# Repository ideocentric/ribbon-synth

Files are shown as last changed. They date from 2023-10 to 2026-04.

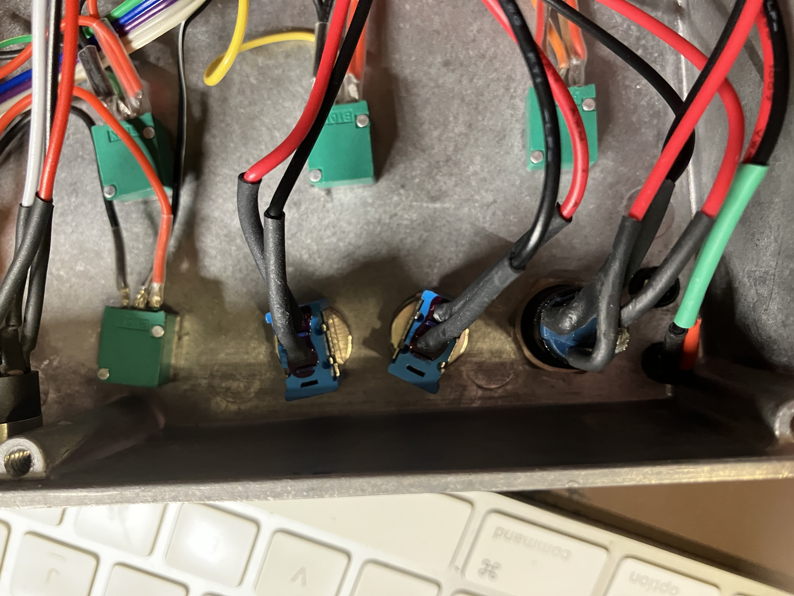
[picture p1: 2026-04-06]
hardware/pcb/absonus-v0.2/hook up/IMG_1601.jpeg

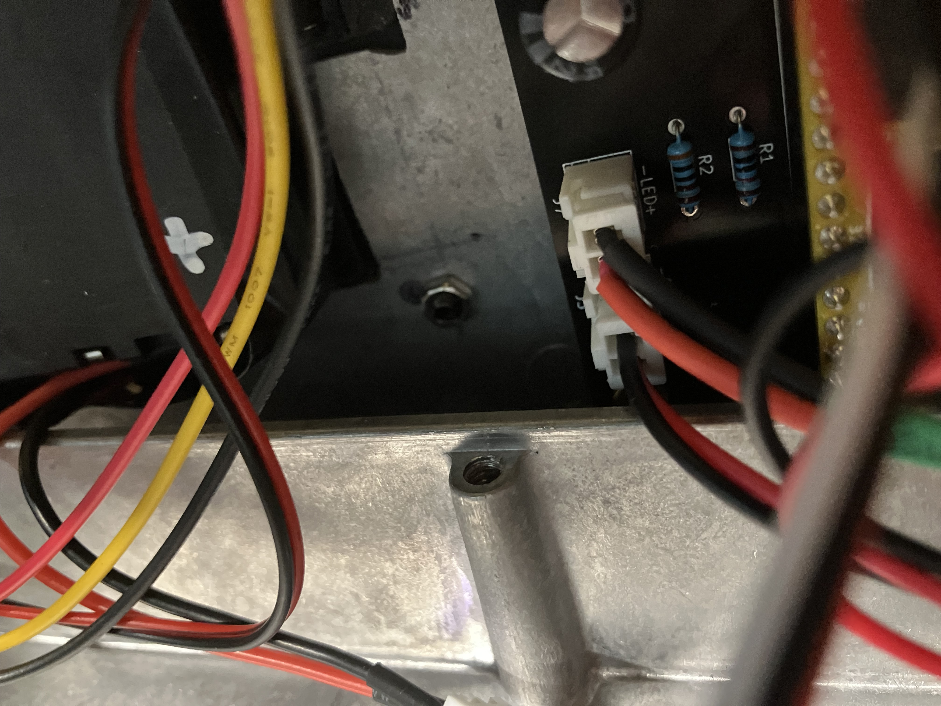
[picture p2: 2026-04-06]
hardware/pcb/absonus-v0.2/hook up/IMG_1600.jpeg

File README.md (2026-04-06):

# absonus — Ribbon Synthesizer

A touch-controlled FM ribbon synthesizer built on the [Electrosmith Daisy Seed](https://electro-smith.com/products/daisy-seed) platform. Pitch is controlled by a 150mm soft-pot ribbon sensor; expression by a force-sensitive resistor. A panel of knobs and switches shapes the FM synthesis, distortion, filter, tremolo, and reverb.

## Repository Structure

```
absonus/
├── firmware/
│   ├── absonus/          Main firmware (DaisyDuino sketch)
│   └── sensor-test/      Utility sketch — reads all panel inputs over serial
│
├── hardware/
│   ├── enclosure/        FreeCAD / DXF / STL files for the enclosure and drill templates
│   ├── pcb/
│   │   ├── absonus-v0.2/ KiCad schematic and PCB layout (current)
│   │   ├── battery-clamp/ 3D-printable clamp for the 18650 battery holder
│   │   └── library/      KiCad component libraries (symbols + footprints)
│   └── testing-panel/    Laser-cut test panel drawings
│
├── bom/
│   ├── pcb-assembly-bom.csv    JLCPCB assembly BOM for the main PCB
│   └── sourced-components.md   Hand-sourced components (pots, sensors, enclosure, etc.)
│
├── docs/
│   ├── design-notes.md         Hardware layout and component design notes
│   ├── firmware-architecture.md Signal chain, module reference, pin mapping
│   └── datasheets/             Component datasheets (FSR, SoftPot, LS18-P, etc.)
│
├── assets/               Photos, renders (to be added)
│
└── archive/
    ├── firmware/         Earlier prototype sketches (fm, fm-chorus, tremor, sensor-test)
    └── hardware/         Earlier PCB revisions (pcb-v0.1, lipo-charger-booster, power-supply)
```

## Documentation

- [Firmware Architecture](docs/firmware-architecture.md) — signal chain, DSP modules, pin mapping, portamento times
- [Design Notes](docs/design-notes.md) — panel layout, Daisy Seed pin assignments, component selection notes
- [Sourced Components BOM](bom/sourced-components.md) — hand-sourced parts with supplier links
- [PCB Assembly BOM](bom/pcb-assembly-bom.csv) — JLCPCB SMT assembly BOM for the main board

## Build

Open `firmware/absonus/absonus.ino` in Arduino IDE with the [DaisyDuino](https://github.com/electro-smith/DaisyDuino) board package installed. Select **Daisy Seed** as the target board.

## Hardware Verification

Before troubleshooting from audio output, flash `firmware/sensor-test/sensor-test.ino` to the Daisy Seed immediately after assembly. It reads every pot, switch, force sensor, and soft-pot and streams their normalized values over serial (9600 baud, 100 ms interval). Use the Arduino Serial Plotter or any serial monitor to confirm each input responds correctly and is wired to the right pin before loading the main firmware.

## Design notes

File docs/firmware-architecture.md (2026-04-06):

# Absonus Firmware Architecture

Firmware for the Absonus ribbon synthesizer. Written in C++ for the Electrosmith Daisy Seed using the DaisyDuino Arduino framework and the DaisySP DSP library.

Source: `firmware/absonus/`

---

## Signal Chain

```
SoftPot (ribbon) ──► pitch (carrierFreq)
FSR (pressure)   ──► gain + gate
                                          ┌─────────┐
                          gate ──────────►│         │
                          gain ──────────►│ Envelope│──► envelopeOut × gain
                                          │  (ADSR) │
                                          └─────────┘
                                                │
                                                ▼
                               ┌─────────────────────────────┐
                  carrierFreq ►│                             │
                   modDepth   ►│       FmChorus              │──► sig (mono)
                   chorusWidth►│  (3-voice FM + detuning)    │
                               └─────────────────────────────┘
                                                │
                                                ▼
                               noiseLevel ──► + WhiteNoise (×0.5 × gain)
                                                │
                                                ▼
                             distortionLevel ──► Cubicnl (cubic waveshaper)
                                                │
                                                ▼
                   filterFreq ──► MoogLadder Filter ◄── filterRes
                                                │
                                                ▼
                                          ┌─────────┐
                  tremoloFreq  ──────────►│         │──► sig × trem (mono)
                  tremoloDepth ──────────►│  Tremor │──► sigl = sig × treml
                  tremoloWidth ──────────►│         │──► sigr = sig × tremr
                                          └─────────┘
                                                │
                                   sigl ────────┤
                                   sigr ────────┤
                                                ▼
                              reverbLevel ──► ReverbSc (SCReverb)
                                                │
                                                ▼
                                 CrossFade (dry/wet blend at reverbLevel)
                                                │
                              volumeLevel ──────┤
                                                ▼
                                     out[0] (L)   out[1] (R)
```

All control parameters are processed through a `Port` (slew/portamento) object before being applied. This prevents zipper noise and audible stepping from ADC readings.

---

## Modules

### FmChorus (`fmchorus.h/.cpp`)

Three-voice frequency modulation synthesizer with built-in chorus detuning.

Each voice is a carrier/modulator oscillator pair (6 oscillators total). The center voice runs at the target pitch. The upper and lower voices are detuned symmetrically by an amount proportional to `width`, up to one equal-tempered semitone. Detuned voices are output at 90% amplitude to preserve the center pitch as dominant.

**Fixed parameters in current patch:**
- Carrier waveform: sawtooth (`WAVE_SAW`)
- Modulator waveform: triangle (`WAVE_TRI`)
- Modulator/carrier ratio: √2 ≈ 1.4142 (equal-tempered tritone)

**Controllable parameters:**
| Parameter | Control | Range | Notes |
|:--|:--|:--|:--|
| Carrier frequency | SoftPot | 55–3520 Hz (A1–A7) | Exponential mapping via `pow(2, normalized × scalar)` |
| Modulation depth | Mod knob (A6\*) | 0.0–1.0 | Scales internally to 0–carrierFreq Hz |
| Chorus width | Chorus knob (A8\*) | 0.0–1.0 | 0 = unison, 1 = ±1 semitone |

*\*See pin mapping below for actual ADC assignments.*

---

### Cubicnl (`cubicnl.h/.cpp`)

Soft-clipping waveshaper using a cubic polynomial. Ported from the Faust `cubicnl.dsp` algorithm by Julius O. Smith III. A DaisySP `DcBlock` filter (pole at 0.999) is applied post-distortion.

| Parameter | Control | Range |
|:--|:--|:--|
| Drive | Distortion knob (A0) | 0.0–1.0 |
| Offset | Fixed | 0.0 (not exposed to panel) |

---

### Tremor (`tremor.h/.cpp`)

Stereo tremolo with panning inspired by the Leslie speaker cabinet. Three internal sine-wave LFOs: one for amplitude modulation and two for stereo panning running at half the tremolo frequency.

The panel uses two toggle switches rather than a continuous knob:

| Switch State | Rate | Depth | Width |
|:--|:--|:--|:--|
| Off (`tremoloOnPin` HIGH) | 0 Hz | 0 | 0 (bypassed) |
| Slow (`tremoloSpeedPin` HIGH) | 1.0 Hz | 0.50 | 0.66 |
| Fast (`tremoloSpeedPin` LOW) | 13.0 Hz | 0.75 | 0.83 |

Slow-to-fast rate transition uses a long portamento time (4 seconds) on `tremoloFreqPortamento` to ramp frequency gradually, mimicking a Leslie speed change.

---

### MoogLadder, ReverbSc, WhiteNoise

Standard DaisySP modules used without modification.

| Module | Control | Range | Notes |
|:--|:--|:--|:--|
| MoogLadder | Cutoff knob (A1\*), Res knob (A5\*) | 20–24000 Hz / 0.0–1.0 | Exponential frequency mapping |
| ReverbSc | Reverb knob (A4\*) | 0.0–1.0 | LP cutoff fixed at 18 kHz; level controls feedback AND dry/wet crossfade |
| WhiteNoise | Noise knob (A2\*) | 0.0–1.0 | Amplitude scaled by ×0.5 × gain |

---

## Envelope and Gate

An ADSR envelope (DaisySP `Adsr`) shapes the amplitude output of `FmChorus`. Gate open/close is driven by the FSR force sensor: gate opens when the normalized FSR reading exceeds `kGateThreshhold` (0.1).

| Segment | Time |
|:--|:--|
| Attack | 100 ms |
| Decay | 100 ms |
| Sustain | 70% |
| Release | 10 ms |

**Frequency hold on gate-off:** When the gate closes, `carrierPortamento` continues slewing toward the *last played frequency* rather than falling back to the minimum. This allows a longer release tail without the pitch dropping to the bottom of the range.

---

## Control Surface Pin Mapping

| ADC Pin | Label | Function | Scaling |
|:--|:--|:--|:--|
| A0 | White | Distortion drive | Linear 0–1 |
| A1 | Purple | Volume | Linear 0–1 |
| A2 | Green | Noise level | Linear 0–1 |
| A3 | Orange | Filter cutoff | Exponential 20–24000 Hz |
| A4 | Pressure | FSR — gain + gate | Linear 0–1, threshold at 0.025 |
| A5 | Ribbon | SoftPot — pitch | Exponential 55–3520 Hz |
| A6 | Yellow | Filter resonance | Linear 0–1 |
| A7 | Blue | Reverb level | Linear 0–1 |
| A8 | Gray | Chorus width | Linear 0–1 |
| A9 | Black | FM modulation depth | Linear 0–1 |
| D13 | SW2 | Tremolo speed (slow/fast) | Digital |
| D14 | SW1 | Tremolo on/off | Digital |

**Sensor thresholds:**
- FSR: readings below 20 (raw) are floored to 0; gate opens above normalized 0.1
- SoftPot: readings below 44 (raw) are floored to 0 to suppress idle noise

---

## Portamento Times

All control parameters are slewed through a `Port` object to eliminate ADC stepping noise. Times below are the slew time constants (seconds to reach ~63% of target).

| Parameter | Slew Time |
|:--|:--|
| Carrier frequency | 10 ms |
| Modulator depth | 10 ms |
| Chorus width | 10 ms |
| Gain | 10 ms |
| Volume | 10 ms |
| Distortion | 10 ms |
| Filter freq | 10 ms |
| Filter res | 10 ms |
| Reverb level | 10 ms |
| Noise level | 10 ms |
| Tremolo frequency | 4000 ms (Leslie ramp) |
| Tremolo depth | 5000 ms |
| Tremolo width | 5000 ms |

---

## Build

Open `firmware/absonus/absonus.ino` in Arduino IDE with the [DaisyDuino](https://github.com/electro-smith/DaisyDuino) board package installed. Select **Daisy Seed** as the target board and upload via the Daisy boot-loader.

### Dependencies
- [DaisyDuino](https://github.com/electro-smith/DaisyDuino) (includes DaisySP)
- All custom DSP modules (`FmChorus`, `Cubicnl`, `Tremor`) are self-contained in the sketch folder.

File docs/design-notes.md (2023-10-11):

# Design Notes

System has 3 potentiometers and 2 toggle switches in the top row.  Second row contains 5 potentiometers.  The third row has a a pressure sensor with a soft potentiometer layered on top of pressure sensor.  Layout of pots, switches and strips are as follows:

Row 1:

| Modulation | Distortion | Chorus Width |  Tremolo Speed| Tremolo On |
|:--|:--|:--|:--|:--|
| 10 - Black | 9 - White | 8 - Gray | SW1 | SW2 |
| A9 | A0 | A8 | D14 | D13 |

Row 2:

| Filter Cutoff | Filter Resonance | Noise | Reverb | Volume |
|:--|:--|:--|:--|:--|
| 3 - Orange | 4 - Yellow | 5 - Green | 6 - Blue | 7 - Purple |
| A3 | A6 | A2 | A7 | A1 |

Touch Sensors:

| Frequency | Pressure |
|:--|:--|
| Soft Pot | Gain |
| A5 | A4 |

Tremolo switches function like a Leslie speaker.  When enabled the speed of the tremolo ramps up to the current speed selection.  The target frequency, depth and stereo width is indicated in the table below:

| Description | Rate | Depth | Width |
|:--|:--|:--|:--|
| Low | 1.0 Hz | 0.5 | 0.66 |
| High | 13 Hz | 0.75 | 0.83 |

Stereo panning is mapped at half the frequency of the tremolo resulting in alternating direction in panning.  The effect is not meant to directly mimic a Leslie speaker, but to simply provide a textural similarity.

Daisy Seed Pin Mappings:

| Pin | Name | Type | Mapping | Notes |
|:-- |:--|:--|:--|:--|
|1 | D0 |  |  |
|2 | D1 |  |  |
|3 | D2 |  |  |
|4 | D3 |  |  |
|5 | D4 |  |  |
|6 | D5 |  |  |
|7 | D6 |  |  |
|8 | D7 |  |  |
|9 | D8 |  |  |
|10 | D9 |  |  |
|11 | D10 |  |  |
|12 | D11 |  |  |
|13 | D12 |  |  |
|14 | D13 | | SW2 |  |
|15 | D14 | | SW1 |  |
|16 | in[0][SIZE] |  |  |
|17 | in[1][SIZE] |  |  |
|18 | out[0][SIZE] |  |  |
|19 | out[1][SIZE] |  |  |
|20 | AGND |  |  |
|21 | 3v3 Analog |  |  |
|22 | A0/D15 | ADC0 | White |  |
|23 | A1/D16 | ADC1 | Purple |  |
|24 | A2/D17 | ADC2 | Green |  |
|25 | A3/D18 | ADC3 | Orange |  |
|26 | A4/D19 | ADC4 | Pressure | 3k Ohm Pulldown |
|27 | A5/D20 | ADC5 | Ribbon | 10k Ohm Pulldown |
|28 | A6/D21 | ADC6 | Yellow |  |
|29 | A7/D22 | ADC7/DAC OUT 2 | Blue |  |
|30 | A8/D23 | ADC8/DAC OUT 1 | Gray |  |
|31 | A9/D24 | ADC9 | Black |  |
|32 | A10/D25 | ADC10 |  |  |
|33 | D26 |  |  |  |
|34 | D27 |  |  |  |
|35 | A11/D28 |  |  |  |
|36 | D29 |  |  |  |
|37 | D30 |  |  |  |
|38 | 3v3 Digital |  |  |  |
|39 | VIN |  | +4v - +17v |  |
|40 | DGND |  |  | | 

Some of the components were challenging to find or were too large for the desired space.  The following list of items are some of the key components required to make this work.  The particular potentiometers were chosen due to their low profile.  The are soldered to a 10 wire ribbon cable.  The colors refer to the matching cable color.

The pressure sensors and soft potentiometers do not match in the available sizes.  In this design I needed a 150mm Soft pot.  Since the Pressure Sensors can be cut down, text available size was 200mm which is cut down to match the usable length of the Soft Pot. 

| Description | Link |
|:--|:--|
| TWTADE 10k Ω Potentiometer | https://www.amazon.com/TWTADE-Amplifier-Potentiometers-Knurled-RK097N-3-10K/dp/B07XQ1Q9RN?th=1 |
| ElectroCookie Solderable Breadboard  | https://www.amazon.com/dp/B07YBYZCTN?ref=ppx_yo2ov_dt_b_product_details&th=1 |
| Ancable 5-Pack 1/8" 3.5mm TRS Stereo Panel Mount Audio AUX Jack | https://www.amazon.com/dp/B07JNC4P7Y?psc=1&ref=ppx_yo2ov_dt_b_product_details |
| uxcell 2 Position 3P SPDT Panel Mount Micro Slide Switch  | https://www.amazon.com/dp/B01NCWDJ18?psc=1&ref=ppx_yo2ov_dt_b_product_details |
| CESS 5.5 x 2.1 mm 5A DC Power Jack Socket  | https://www.amazon.com/dp/B07FK6MMGH?psc=1&ref=ppx_yo2ov_dt_b_product_details |
| Bud Industries Aluminum Enclosure 7.39” L x4.7” W x 1.5” H | https://www.amazon.com/dp/B005T7R82W?psc=1&ref=ppx_yo2ov_dt_b_product_details |
| LS18-P 3-Channel NoBounce IC – PDIP | https://logiswitch.com/shop/nobounce-ics/ls18-p/ |
| Force Sensor FSR Model 408 (200mm length) | https://buyinterlinkelectronics.com/collections/new-standard-force-sensors/products/fsr-model-408-200mm-length |
| Soft Pot (150mm) | https://store.spectrasymbol.com/products/softpot-linear-potentiometer?variant=40669007904883 |

The general design of the instrument is based on a simple FM synthesis.  The module uses 3 carriers and modulator pairs.  The carrier wave form is a sawtooth wave while the modulator is a triangle wave.  The synthesis module is designed to have the ration of the modulator to carrier as configurable, however, in this design it is set to an equal-tempered tritone.  The depth extends the modulation from 0 - the carrier frequency.  The “Chorus Width” is essentially a 3 voice detuning from no detuning  to a full equal-tempered semi-tone.  The upper and lower voices are at a slightly lower amplitude to retain the center frequencies dominance.  The detuned components are a full FM carrier/modulator pair.

Distortion is implemented using Julius O. Smith’s cubicnl.dsp algorithm from Faust ported to the Daisy Seed here.

The Moog Ladder Filter, White Noise and the SCReverb are standard Daisy Seed modules are used here without modification.

One of the initial challenges was to evaluate and map the Soft Pot and Force Sensors.  The Soft Pot is a bit noisy when idle and the full reading needs to be mapped to a usable range.  Additionally, the gate release locks the last set frequency  in order to prevent a fall off to the lowest frequency.  This allows for extending the release time of an envelope.

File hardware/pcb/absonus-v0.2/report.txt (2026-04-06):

Info: Output directory '/Users/matt/Documents/GitHub/synths/daisy/ribbon-synth/hardware/pcb/absonus-v0.2/gerbers' created.
Plotted to '/Users/matt/Documents/GitHub/synths/daisy/ribbon-synth/hardware/pcb/absonus-v0.2/gerbers/absonus-v0.2-F_Cu.gbr'.
Plotted to '/Users/matt/Documents/GitHub/synths/daisy/ribbon-synth/hardware/pcb/absonus-v0.2/gerbers/absonus-v0.2-B_Cu.gbr'.
Plotted to '/Users/matt/Documents/GitHub/synths/daisy/ribbon-synth/hardware/pcb/absonus-v0.2/gerbers/absonus-v0.2-F_Paste.gbr'.
Plotted to '/Users/matt/Documents/GitHub/synths/daisy/ribbon-synth/hardware/pcb/absonus-v0.2/gerbers/absonus-v0.2-B_Paste.gbr'.
Plotted to '/Users/matt/Documents/GitHub/synths/daisy/ribbon-synth/hardware/pcb/absonus-v0.2/gerbers/absonus-v0.2-F_Silkscreen.gbr'.
Plotted to '/Users/matt/Documents/GitHub/synths/daisy/ribbon-synth/hardware/pcb/absonus-v0.2/gerbers/absonus-v0.2-B_Silkscreen.gbr'.
Plotted to '/Users/matt/Documents/GitHub/synths/daisy/ribbon-synth/hardware/pcb/absonus-v0.2/gerbers/absonus-v0.2-F_Mask.gbr'.
Plotted to '/Users/matt/Documents/GitHub/synths/daisy/ribbon-synth/hardware/pcb/absonus-v0.2/gerbers/absonus-v0.2-B_Mask.gbr'.
Plotted to '/Users/matt/Documents/GitHub/synths/daisy/ribbon-synth/hardware/pcb/absonus-v0.2/gerbers/absonus-v0.2-Edge_Cuts.gbr'.
Plotted to '/Users/matt/Documents/GitHub/synths/daisy/ribbon-synth/hardware/pcb/absonus-v0.2/gerbers/absonus-v0.2-F_Courtyard.gbr'.
Created Gerber job file '/Users/matt/Documents/GitHub/synths/daisy/ribbon-synth/hardware/pcb/absonus-v0.2/gerbers/absonus-v0.2-job.gbrjob'.
Info: Done.
Info: Done.

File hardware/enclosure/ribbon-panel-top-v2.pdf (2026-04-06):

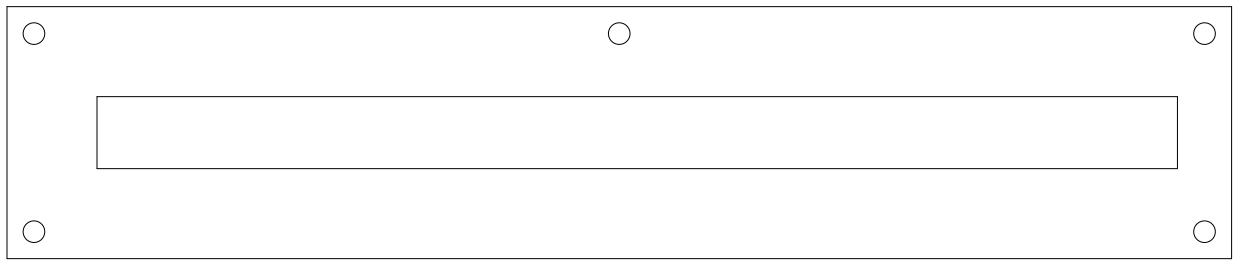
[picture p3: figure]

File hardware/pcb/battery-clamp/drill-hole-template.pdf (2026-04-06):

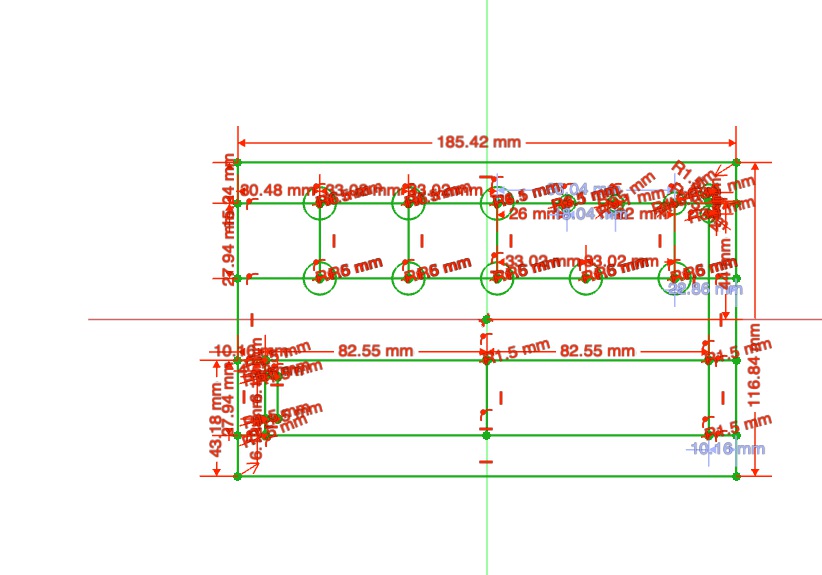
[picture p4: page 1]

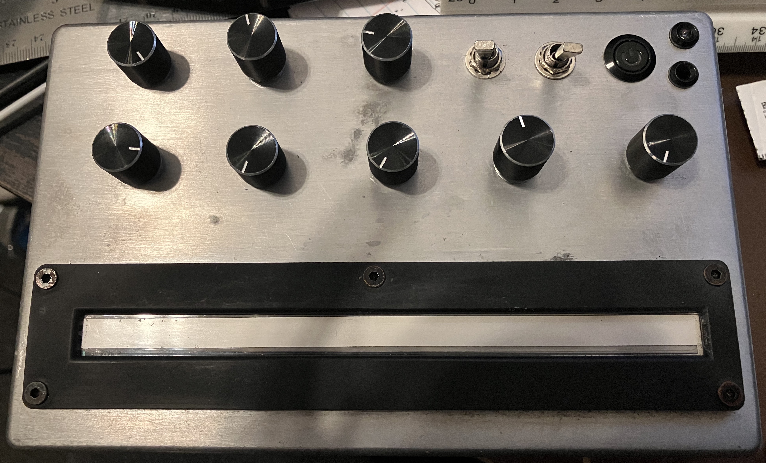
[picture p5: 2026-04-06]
hardware/enclosure/enclosure/top.jpg

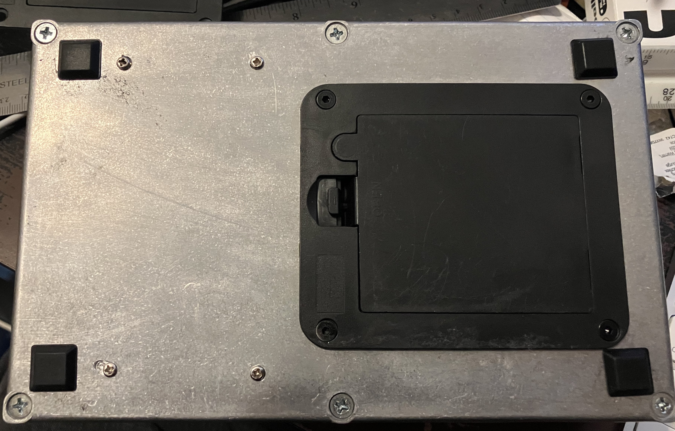
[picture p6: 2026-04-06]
hardware/enclosure/enclosure/back.jpg

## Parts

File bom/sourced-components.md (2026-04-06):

# Sourced Components — Absonus

Components not included in the JLCPCB PCB assembly BOM. These are sourced separately and installed by hand.

| Description | Source / Link |
|:--|:--|
| TWTADE 10kΩ Potentiometer (RK097N-3) | [Amazon](https://www.amazon.com/TWTADE-Amplifier-Potentiometers-Knurled-RK097N-3-10K/dp/B07XQ1Q9RN?th=1) |
| ElectroCookie Solderable Breadboard | [Amazon](https://www.amazon.com/dp/B07YBYZCTN) |
| Ancable 1/8" 3.5mm TRS Stereo Panel Mount Audio Jack (5-pack) | [Amazon](https://www.amazon.com/dp/B07JNC4P7Y) |
| uxcell 2-Position 3P SPDT Panel Mount Micro Slide Switch | [Amazon](https://www.amazon.com/dp/B01NCWDJ18) |
| CESS 5.5×2.1mm 5A DC Power Jack Socket | [Amazon](https://www.amazon.com/dp/B07FK6MMGH) |
| Bud Industries Aluminum Enclosure 7.39"L × 4.7"W × 1.5"H | [Amazon](https://www.amazon.com/dp/B005T7R82W) |
| LS18-P 3-Channel NoBounce IC (PDIP) | [LogiSwitch](https://logiswitch.com/shop/nobounce-ics/ls18-p/) |
| Force Sensor FSR Model 408 (200mm length) | [Interlink Electronics](https://buyinterlinkelectronics.com/collections/new-standard-force-sensors/products/fsr-model-408-200mm-length) |
| SoftPot Linear Potentiometer (150mm) | [Spectra Symbol](https://store.spectrasymbol.com/products/softpot-linear-potentiometer?variant=40669007904883) |

## Notes

- The 10kΩ potentiometers were chosen for their low profile; they are soldered to a 10-wire ribbon cable with color-coded conductors matching the panel layout (see `docs/design-notes.md`).
- The FSR is 200mm and is cut down to match the usable 150mm length of the SoftPot.
- A 3kΩ pulldown resistor is required on the FSR input (A4/D19) and a 10kΩ pulldown on the SoftPot input (A5/D20).

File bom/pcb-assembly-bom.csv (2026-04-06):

Designator | Footprint | Quantity | Value | LCSC Part #
A1 | Electrosmith_Daisy_Seed | 1 | Daisy_Seed_Rev4
A2, A3 | PinHeader_1x20_P2.54mm_Vertical | 2 | PinHeader_1x20_P2.54mm_Vertical | C2897383
C1 | CP_Elec_5x5.4 | 1 | 220uF | C3337
H1, H2, H3, H4 | MountingHole_3.2mm_M3 | 4 | M3
J1 | JST_SH_SM04B-SRSS-TB_1x04-1MP_P1.00mm_Horizontal | 1 | i2c Qwiic | C160404
J10 | IDC-Header_2x05_P2.54mm_Vertical | 1 | 2x5 IDC | C4749194
J3 | JST_XH_B2B-XH-A_1x02_P2.50mm_Vertical | 1 | DC 5V | C158012
J4 | JST_XH_B2B-XH-A_1x02_P2.50mm_Vertical | 1 | Pressure | C158012
J5 | JST_XH_B2B-XH-A_1x02_P2.50mm_Vertical | 1 | SW1 | C158012
J6 | JST_XH_B2B-XH-A_1x02_P2.50mm_Vertical | 1 | SW2 | C158012
J7 | JST_XH_B2B-XH-A_1x02_P2.50mm_Vertical | 1 | LED | C158012
J8 | JST_XH_B3B-XH-A_1x03_P2.50mm_Vertical | 1 | Position | C144394
J9 | JST_XH_B3B-XH-A_1x03_P2.50mm_Vertical | 1 | Audio Out | C144394
R1 | 0603 | 1 | 10k | C15401
R2 | 0603 | 1 | 3k | C4211
U1 | DIP787W45P254L927H533Q8 | 1 | LS18-P | C5289485

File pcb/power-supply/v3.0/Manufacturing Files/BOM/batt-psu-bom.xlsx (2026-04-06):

Comment | MFR | MFR-PN | Designator | Footprint | JLCPCB Part #（optional）
BH-18650-A5BJ001-2D | MYOUNG | BH-18650-A5BJ001-2D | BT1, BT2 | Battery:BatteryHolder_MPD_BH-18650-PC2 | C19184083
CL10A106MA8NRNC | Samsung Electro-Mechanics | CL10A106MA8NRNC | C1, C7, C10, C16 | Capacitor_SMD:C_0603_1608Metric | C96446
RVT1A471M0607 | Honor Elec | RVT1A471M0607 | C2 | Capacitor_SMD:CP_Elec_6.3x7.7 | C87858
0603B104K250CT | Walsin Tech Corp | 0603B104K250CT | C3, C4, C5, C13 | Capacitor_SMD:C_0603_1608Metric | C83054
0603X105M250NT | FH (Guangdong Fenghua Advanced Tech) | 0603X105M250NT | C6, C14 | Capacitor_SMD:C_0603_1608Metric | C2857985
CL21A226MAYNNNE | Samsung Electro-Mechanics | CL21A226MAYNNNE | C8 | Capacitor_SMD:C_0603_1608Metric | C602037
SS34 | JUXING | SS34 | D3 | Diode_SMD:D_SMA | C3011102
B2B-XH-A(LF)(SN) | JST | B2B-XH-A(LF)(SN) | J1, J2, J3, J5, J6, J7 | Connector_JST:JST_XH_B2B-XH-A_1x02_P2.50mm_Vertical | C158012
SLO1040H100MTT | Sunltech Tech | SLO1040H100MTT | L1 | Inductor_SMD:L_Wuerth_HCI-1040 | C182194
SI2347DS-T1-GE3 | Vishay Intertech | SI2347DS-T1-GE3 | Q1, Q2 | Package_TO_SOT_SMD:SOT-23 | C145002
FS3402 | FOSAN | FS3402 | Q3, Q4, Q5 | Package_TO_SOT_SMD:SOT-23 | C2926128
FRC0603J474 TS | FOJAN | FRC0603J474 TS | R1 | Resistor_SMD:R_0603_1608Metric | C2907171
FRC0603J331 TS | FOJAN | FRC0603J331 TS | R2, R3, R7, R9, R11 | Resistor_SMD:R_0603_1608Metric | C2907152
FRC0603J202 TS | FOJAN | FRC0603J202 TS | R4 | Resistor_SMD:R_0603_1608Metric | C2907137
FRC0603F6201TS | FOJAN | FRC0603F6201TS | R5 | Resistor_SMD:R_0603_1608Metric | C2907054
FRC0603J202 TS | FOJAN | FRC0603J202 TS | R6 | Resistor_SMD:R_0603_1608Metric | C2907137
25121WF800MT4E | UNI-ROYAL(Uniroyal Elec) | 25121WF800MT4E | R12 | Resistor_SMD:R_2512_6332Metric | C421509
MIC39102YM-TR | Microchip Tech | MIC39102YM-TR | U1 | Package_SO:SOIC-8_3.9x4.9mm_P1.27mm | C627993
HY2120-CB | HYCON Tech | HY2120-CB | U3 | Package_TO_SOT_SMD:SOT-23-6 | C116509
LTC4412ES6#TRPBF | Analog Devices | LTC4412ES6#TRPBF | U4 | Package_TO_SOT_SMD:TSOT-23-6 | C514442
CN3302 | ShangHai Consonance Elec | CN3302 | U5 | Package_SO:SOIC-8_3.9x4.9mm_P1.27mm | C559039

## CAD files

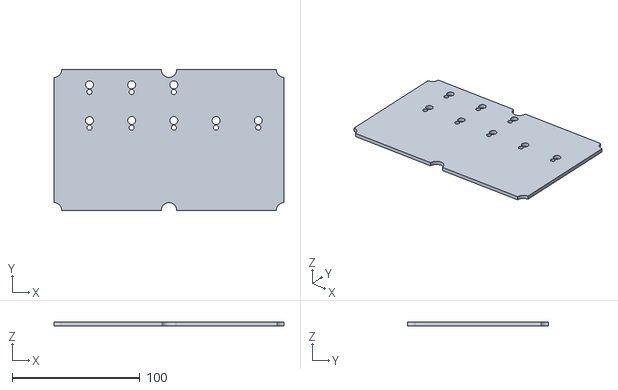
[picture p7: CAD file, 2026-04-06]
hardware/enclosure/internal-drill-holes-test.stl
180.0 x 110.0 x 3.00

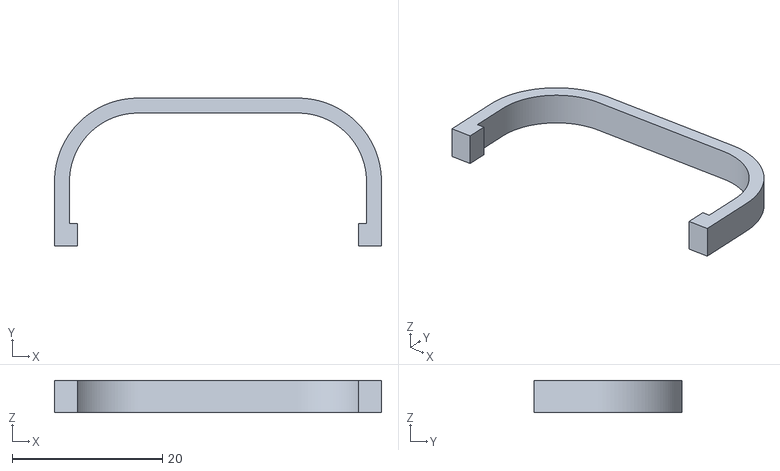
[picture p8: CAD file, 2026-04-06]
hardware/pcb/battery-clamp/battery-clamp-BodyPad.stl
43.6 x 19.7 x 4.30

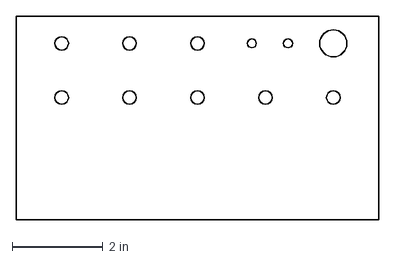
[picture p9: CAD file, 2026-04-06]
hardware/testing-panel/test-panel.dxf
8.00 x 4.50 in

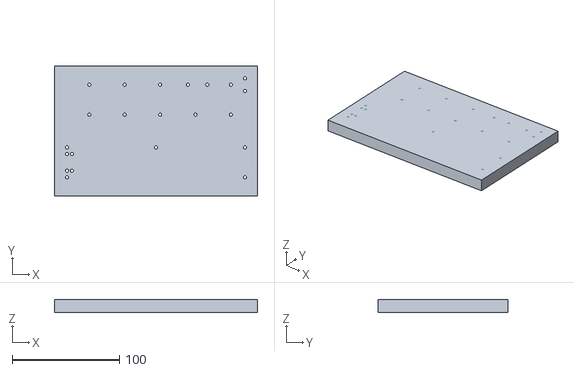
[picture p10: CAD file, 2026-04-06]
hardware/enclosure/drill-hole-template-v5.stl
189.4 x 120.8 x 12.0

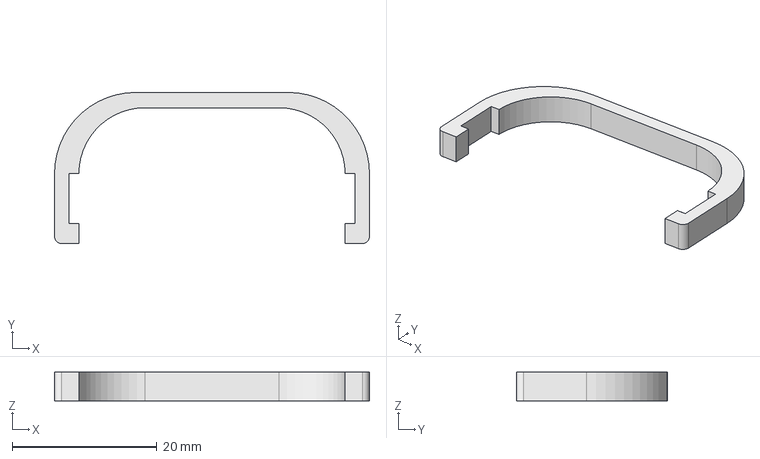
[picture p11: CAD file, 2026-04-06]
hardware/pcb/battery-clamp/battery-clamp-v3.FCStd
43.6 x 20.9 x 4.00 mm

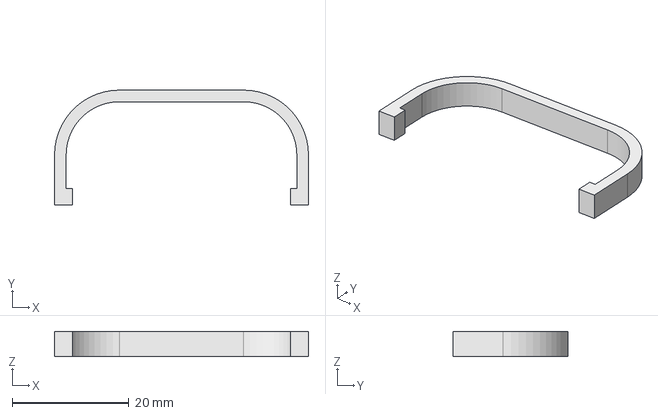
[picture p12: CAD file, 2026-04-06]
hardware/pcb/battery-clamp/battery-clamp.FCStd
43.6 x 19.7 x 4.30 mm

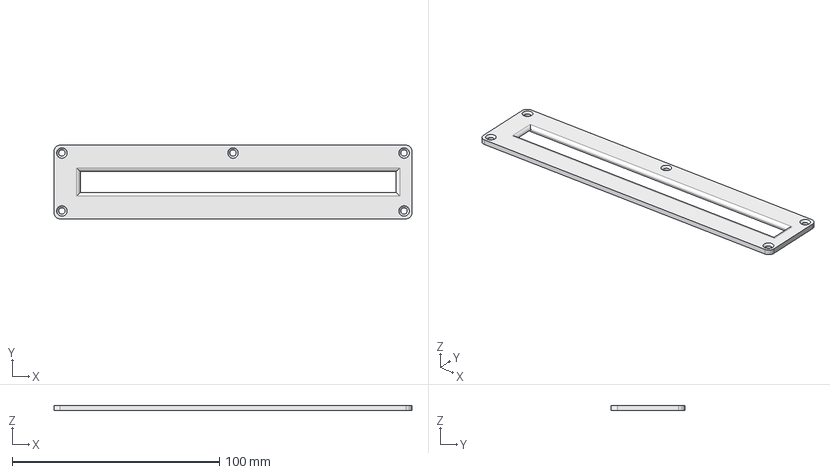
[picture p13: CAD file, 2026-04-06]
hardware/enclosure/ribbon-panel-rev-1.0.FCStd
172.7 x 35.6 x 2.50 mm

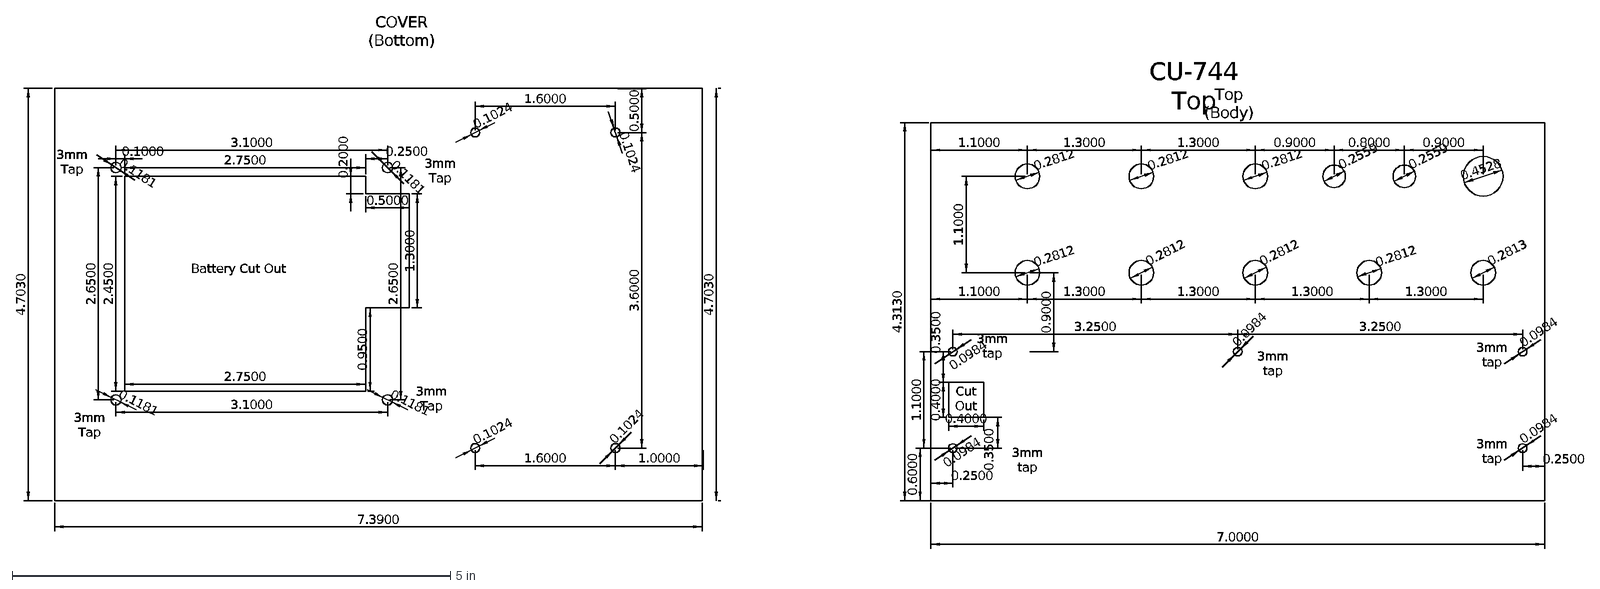
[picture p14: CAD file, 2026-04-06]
hardware/enclosure/#bud-cu-477-drill-patterns.dxf
7.3900
4.7030
COVER (Bottom)
4.3130
7.0000
3.2500
1.1000
0.4000
0.3500
0.6000
0.0984
0.2559
0.2812
0.2813
Top (Body)
0.2500
1.3000
0.9000
3mm tap
CU-744 Top
1.6000
0.5000
3.6000
1.0000
0.1024
3.1000
2.6500
0.1000
2.7500
2.4500
0.9500
0.2000
0.1181
3mm Tap
Battery Cut Out
Cut Out
0.4528
0.8000

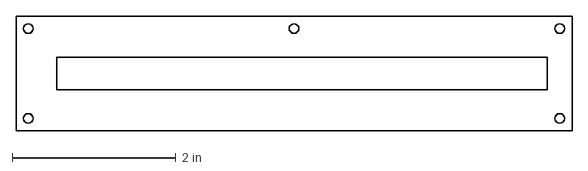
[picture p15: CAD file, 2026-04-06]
hardware/enclosure/ribbon-panel-top-rev-1.0.dxf
6.80 x 1.40 in

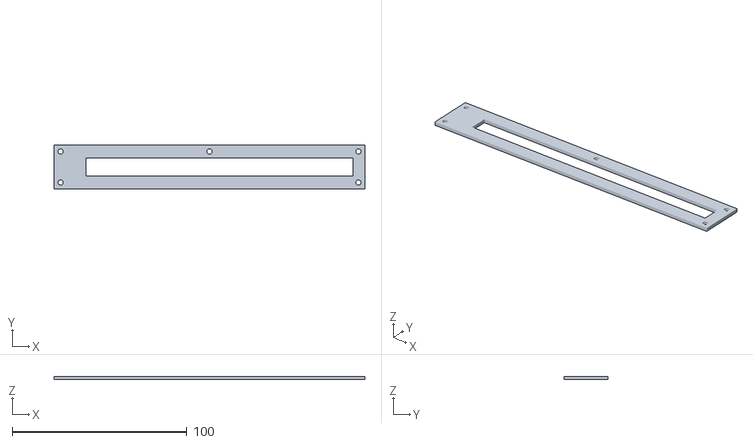
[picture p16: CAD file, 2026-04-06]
hardware/enclosure/ribbon-panel-larger.stl
177.8 x 25.3 x 2.00

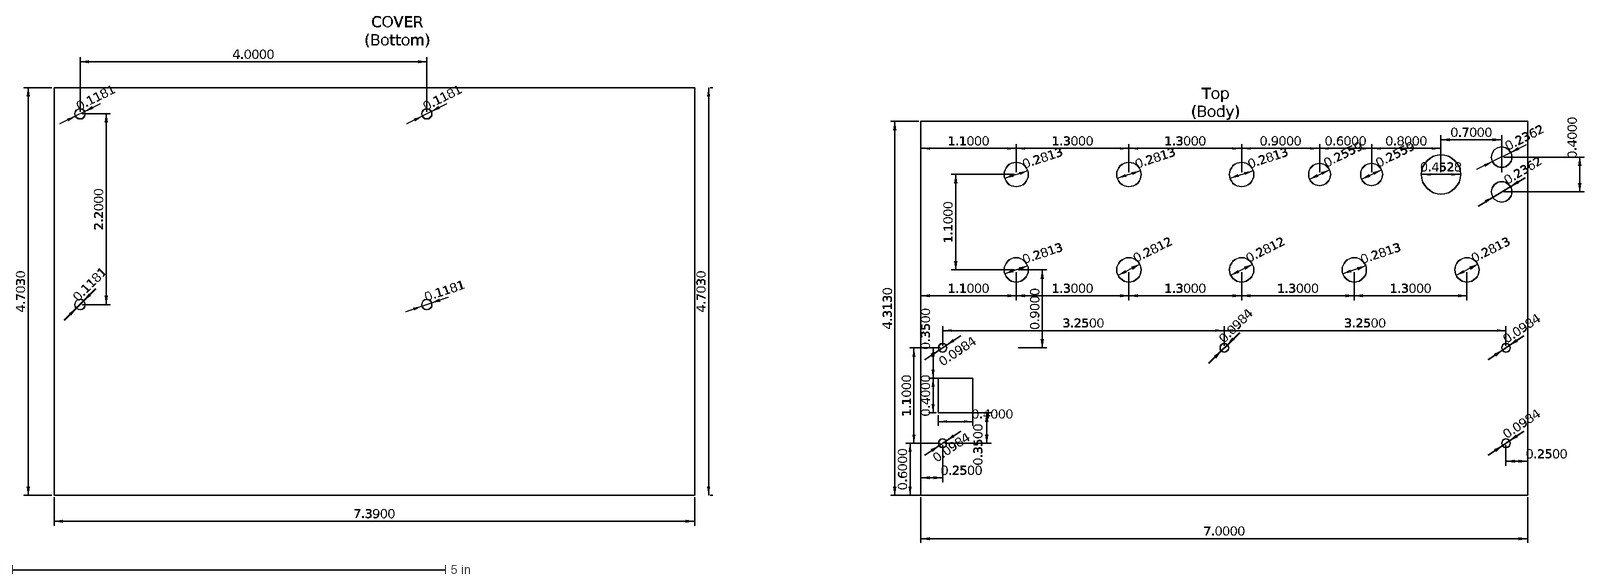
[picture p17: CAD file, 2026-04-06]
hardware/enclosure/bud-industries-custom-drill.dxf
7.3900
4.7030
4.0000
2.2000
0.1181
COVER (Bottom)
4.3130
7.0000
3.2500
1.1000
0.4000
0.3500
0.6000
0.0984
0.2362
0.4528
0.2559
0.2813
0.2812
Top (Body)
0.2500
1.3000
0.9000
0.8000
0.7000

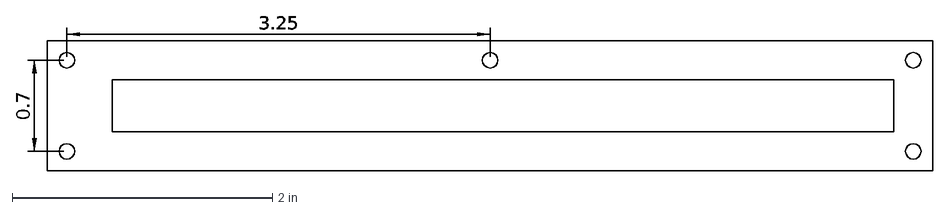
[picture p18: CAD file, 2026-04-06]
hardware/enclosure/#ribbon-panel-top.dxf
3.25
0.7

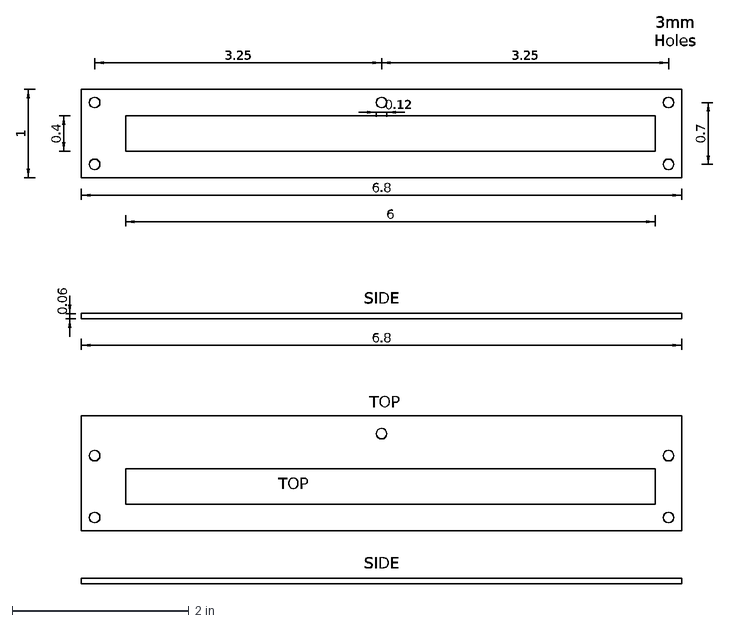
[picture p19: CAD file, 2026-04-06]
hardware/enclosure/#ribbon-panel-v2.dxf
TOP
SIDE
6.8
6
0.4
3.25
0.7
1
0.06
0.12
3mm Holes

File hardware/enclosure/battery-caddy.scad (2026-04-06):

difference(){
cube([2.4,2.8,1]);
translate([0.1,-0.1,0.1]){
cube([2.2,2.8,2]);
};

translate([0.4, 0.4, -0.1]){
 cylinder(0.4,0.06,0.06, $fn=24);
};
translate([2, 0.4, -0.1]){
 cylinder(0.4,0.06,0.06, $fn=24);
};

translate([0.4, 2.4, -0.1]){
 cylinder(0.4,0.06,0.06, $fn=24);
};
translate([2, 2.4, -0.1]){
 cylinder(0.4,0.06,0.06, $fn=24);
};

};

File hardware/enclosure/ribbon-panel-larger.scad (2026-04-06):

$fn=96;
px = 7 * 25.4;
py = .8 * 25.4 +3 +2;
pz = 2;

ix = 6 * 25.4;
iy = 0.4 * 25.4;
iz = 2 + 2;  // adding 2 for offset

radius = 3/2;
offset = (py-iy)/4;

module hole(x,y) 
{
    translate([x,y,-1])
    {
        cylinder(4,radius,radius);
    };
};
module plate() {
    cube([px, py, pz]);
};

module innerCutout() {
    translate([px-7-ix,(py-iy)/2,-1])
    {
        cube([ix,iy,iz]);
    };
}

difference()
{
    plate();
    innerCutout();
    
    hole(offset,offset);
    hole(offset,py-offset);
    hole(px-offset,offset);
    hole(px-offset,py-offset); 
    hole(px/2,py-offset); 
};

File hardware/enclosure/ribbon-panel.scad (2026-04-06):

difference(){
union(){
cube([0.3, 6.8, 0.0625]);
translate([0.3, 0.0]) {
    cube([0.4,0.4, 0.0625]);
    };
    translate([0.7,0,0]) {
        cube([0.3, 6.8, 0.0625]);
        };
 translate([0.3,6.5,0.0]){
     cube([0.4,0.3, 0.0625]);
 };
};

translate([0.13,0.13,-0.05]){
cylinder(0.1625,0.06, 0.06, $fn=45);
};
translate([0.87,0.13,-0.05]){
cylinder(0.1625,0.06, 0.06, $fn=45);
};

translate([0.13,6.67,-0.05]){
cylinder(0.1625,0.06, 0.06, $fn=45);
};
translate([0.87,6.67,-0.05]){
cylinder(0.1625,0.06, 0.06, $fn=45);
};

translate([0.13,3.4,-0.05]){
cylinder(0.1625,0.06, 0.06, $fn=45);
};


};

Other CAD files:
hardware/enclosure/bottom-drill-holes.FCStd
hardware/enclosure/internal-drill-holes-blank.stl
hardware/enclosure/internal-drill-holes.step
hardware/enclosure/bottom-drill-holes-BodyPad.stl
hardware/enclosure/drill-hole-template.FCStd
hardware/enclosure/#internal-drill-holes.dxf
hardware/enclosure/18560-battery-case.FCStd
hardware/enclosure/bud-cu-477-drill-patterns.dxf
hardware/enclosure/drill-hole-template-v1.stl
hardware/enclosure/drill-hole-template-v2.stl
hardware/enclosure/drill-hole-template-v3.stl
hardware/enclosure/drill-hole-template-v4.stl
hardware/enclosure/enclosure-v2.dxf
hardware/enclosure/internal-drill-holes.FCStd
hardware/enclosure/internal-drill-holes.dxf
hardware/enclosure/internal-drill-holes.stl
hardware/enclosure/ribbon-panel-rev-1.0.stl
hardware/enclosure/ribbon-panel-rev-1.2.step
hardware/enclosure/ribbon-panel-rev-1.2.stl
hardware/enclosure/ribbon-panel-top.dxf
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

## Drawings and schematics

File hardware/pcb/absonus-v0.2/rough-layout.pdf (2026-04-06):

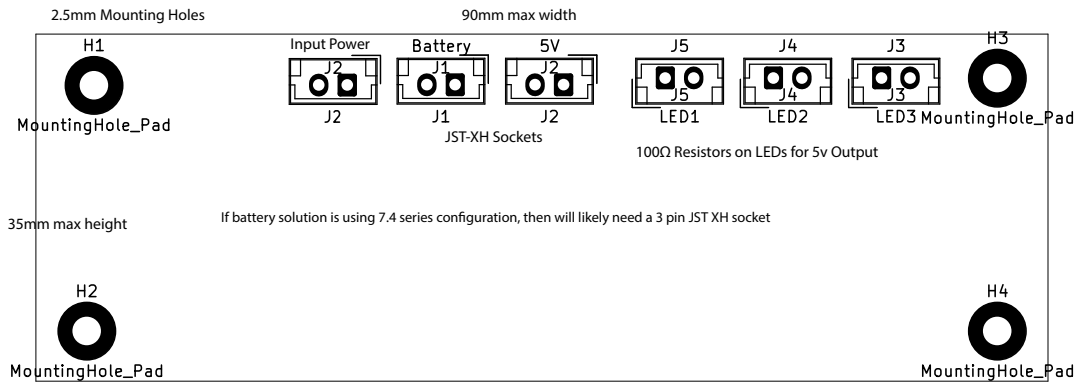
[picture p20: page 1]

100Ω Resistors on LEDs for 5v Output

If battery solution is using 7.4 series conguration, then will likely need a 3 pin JST XH socket

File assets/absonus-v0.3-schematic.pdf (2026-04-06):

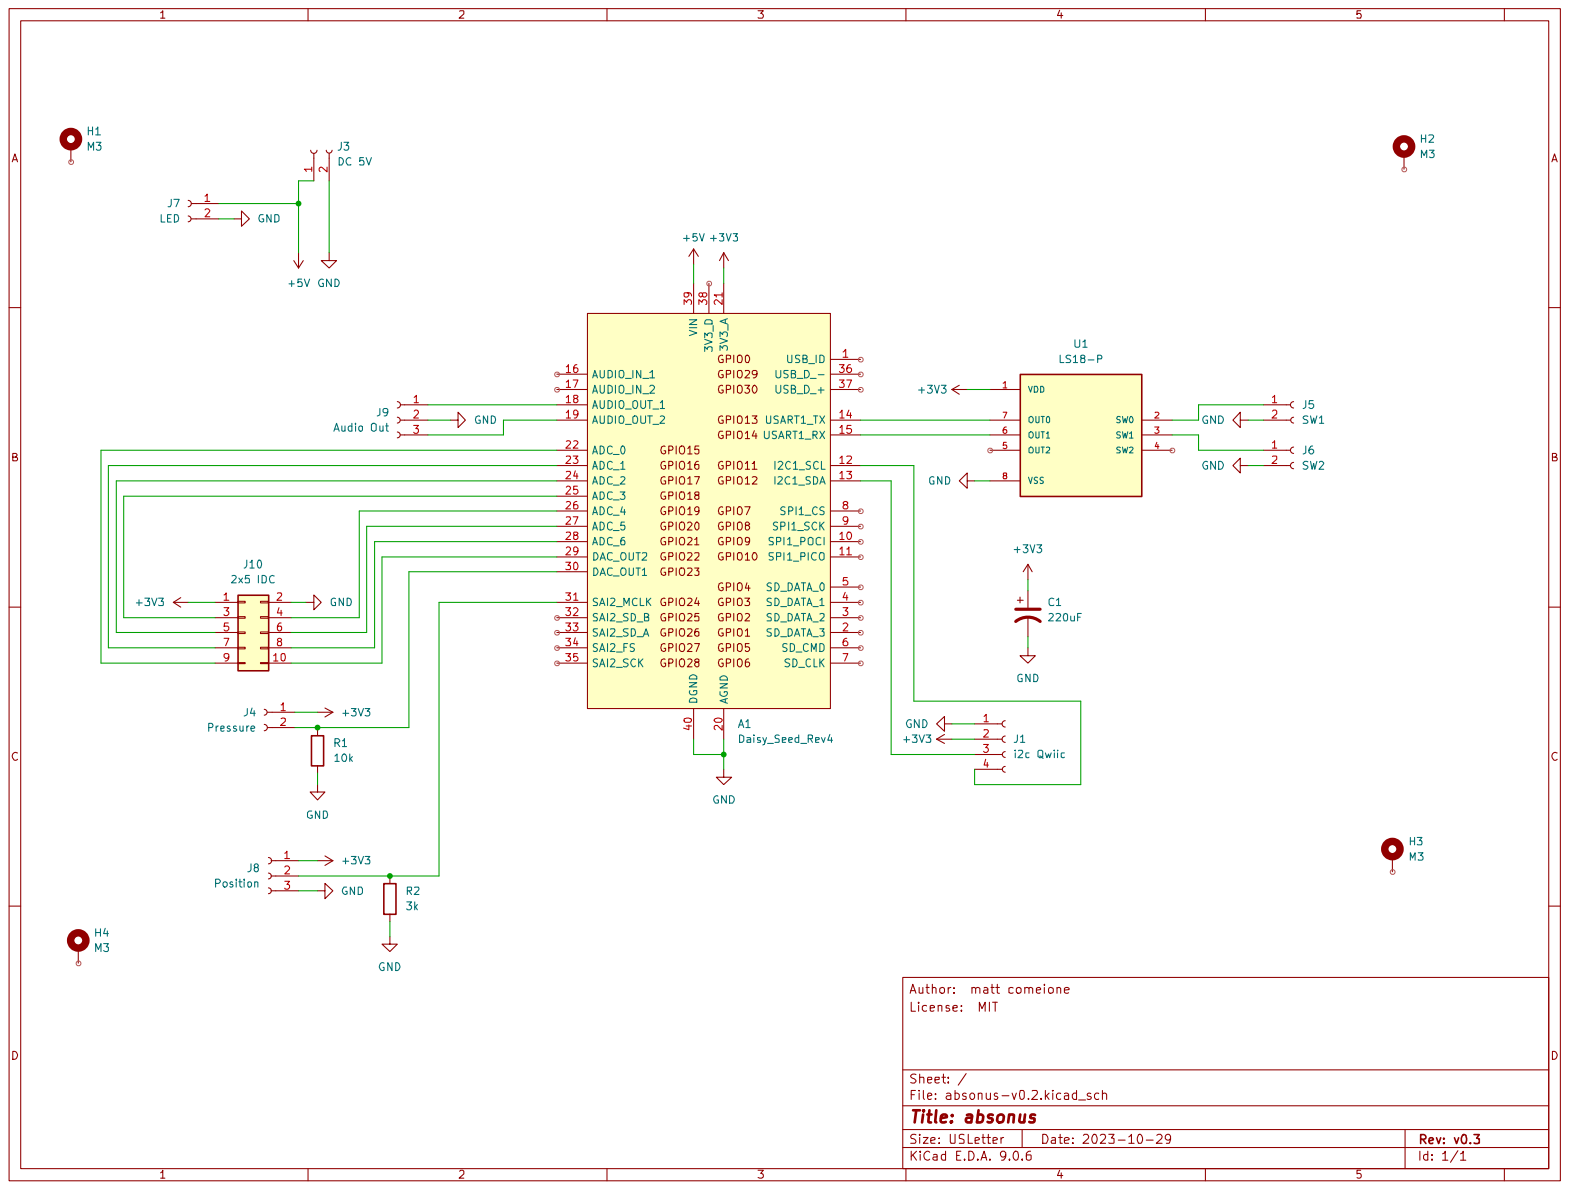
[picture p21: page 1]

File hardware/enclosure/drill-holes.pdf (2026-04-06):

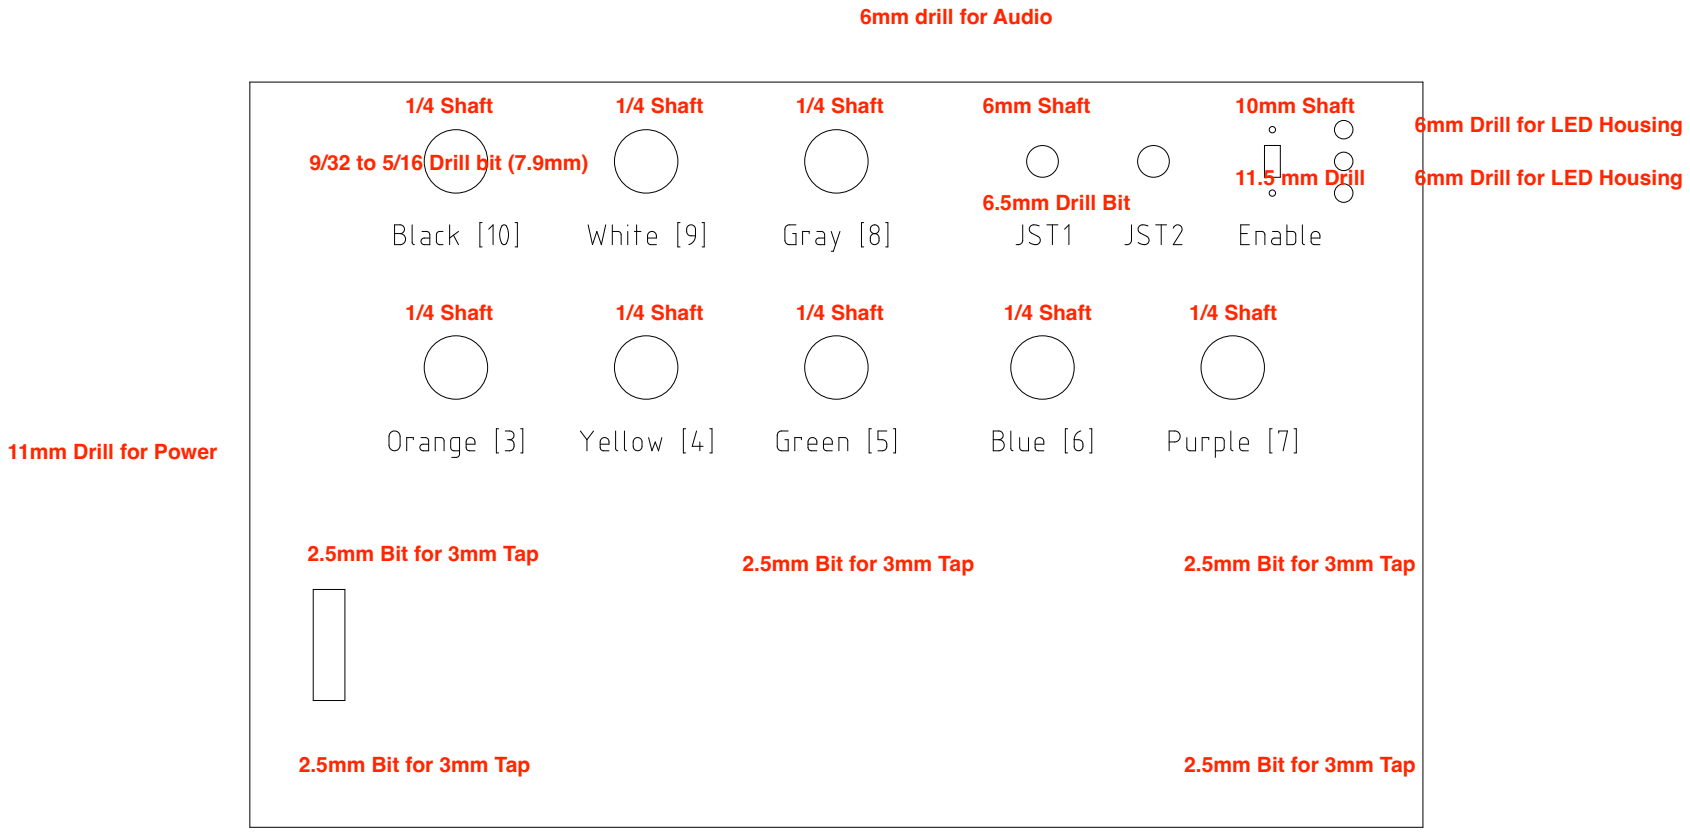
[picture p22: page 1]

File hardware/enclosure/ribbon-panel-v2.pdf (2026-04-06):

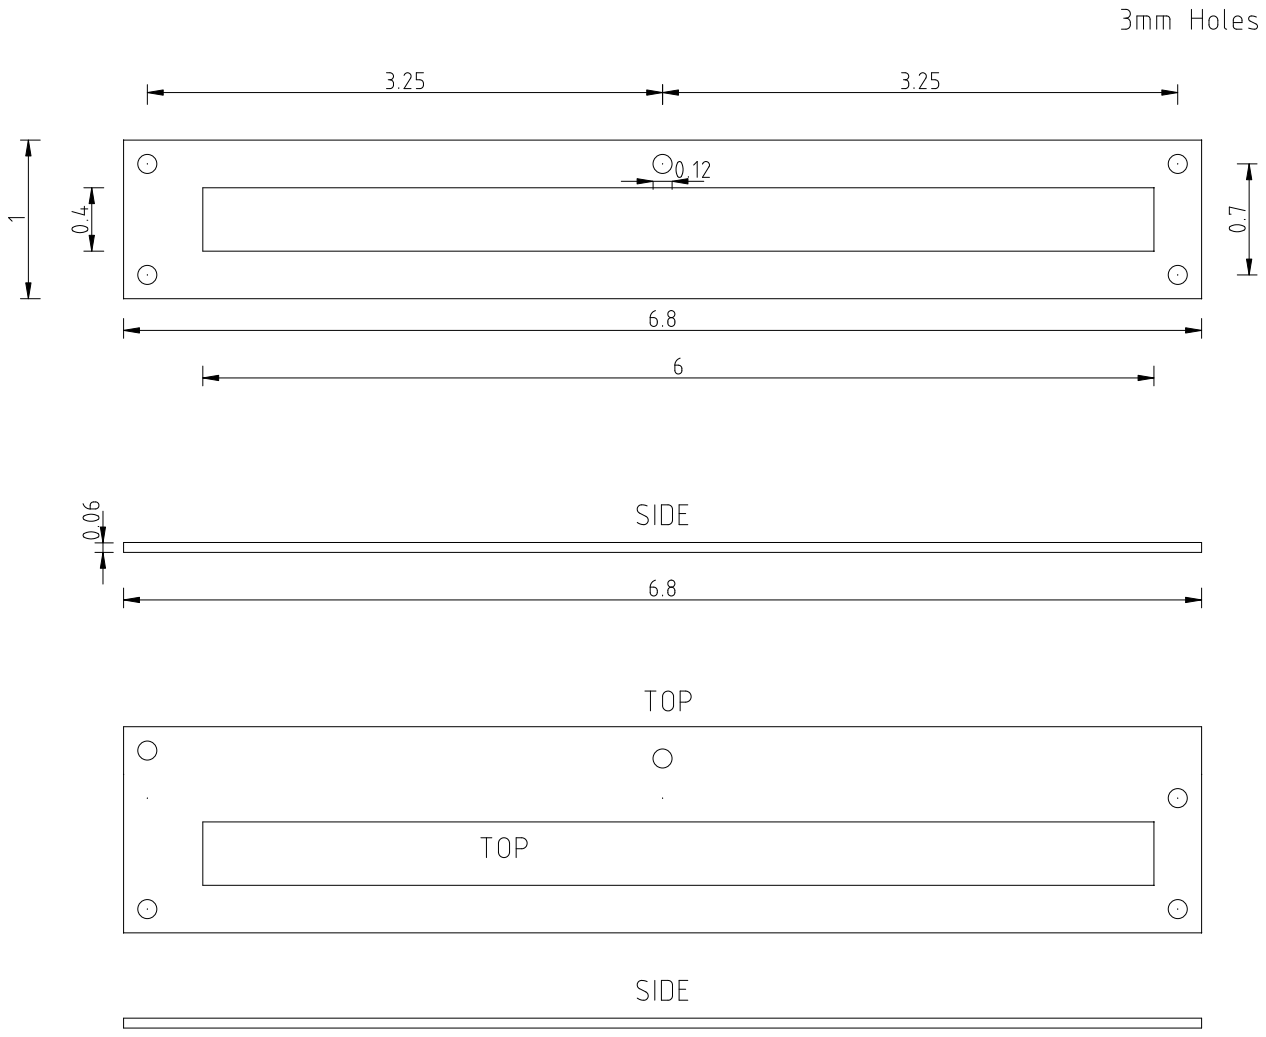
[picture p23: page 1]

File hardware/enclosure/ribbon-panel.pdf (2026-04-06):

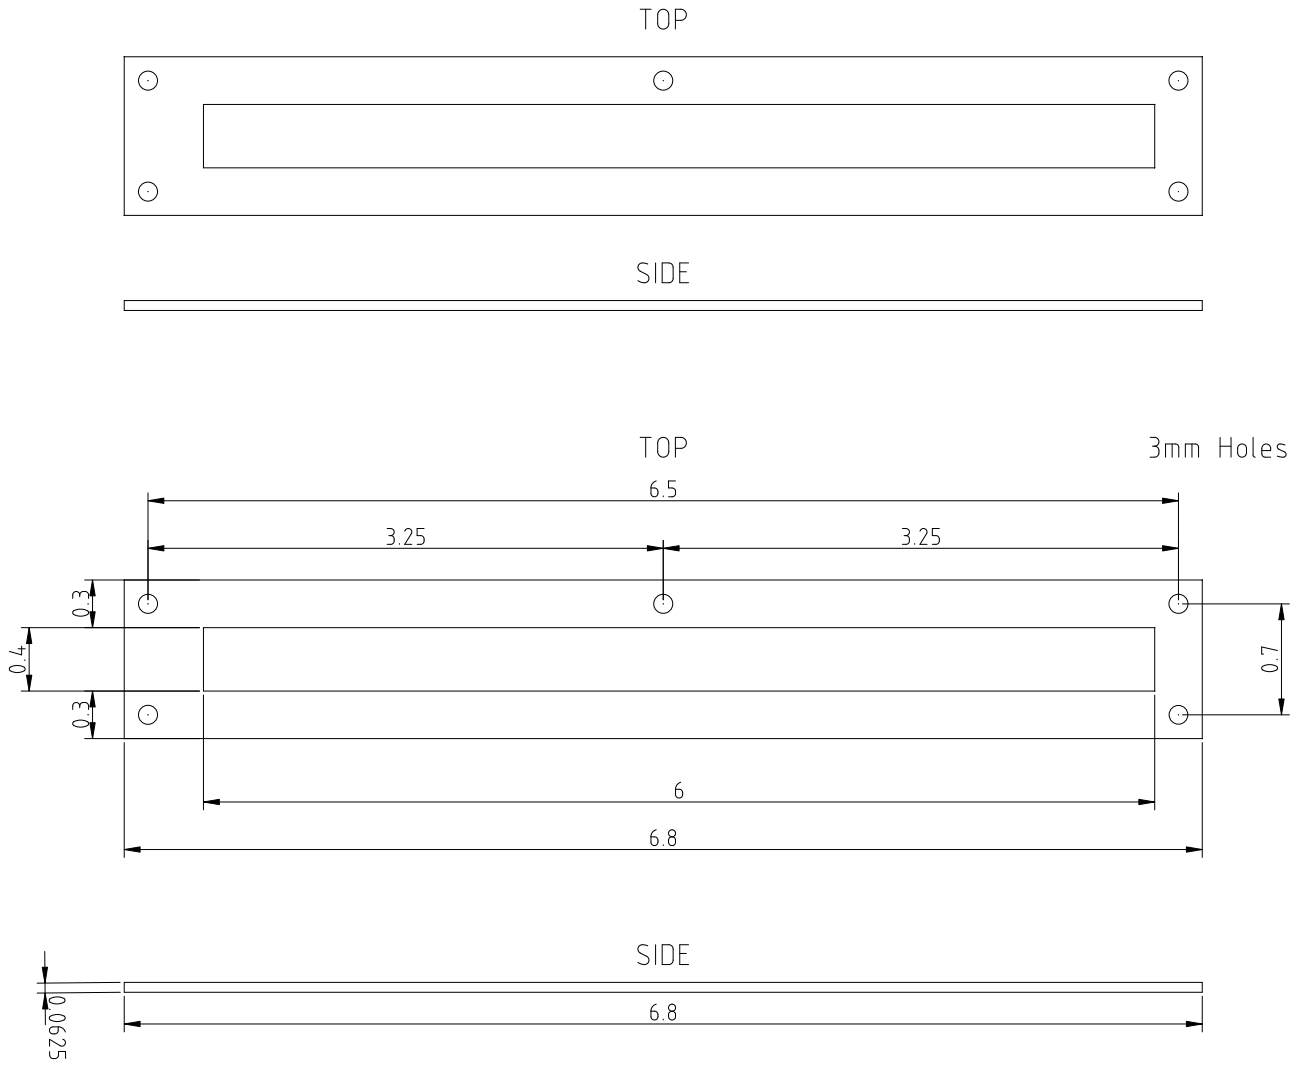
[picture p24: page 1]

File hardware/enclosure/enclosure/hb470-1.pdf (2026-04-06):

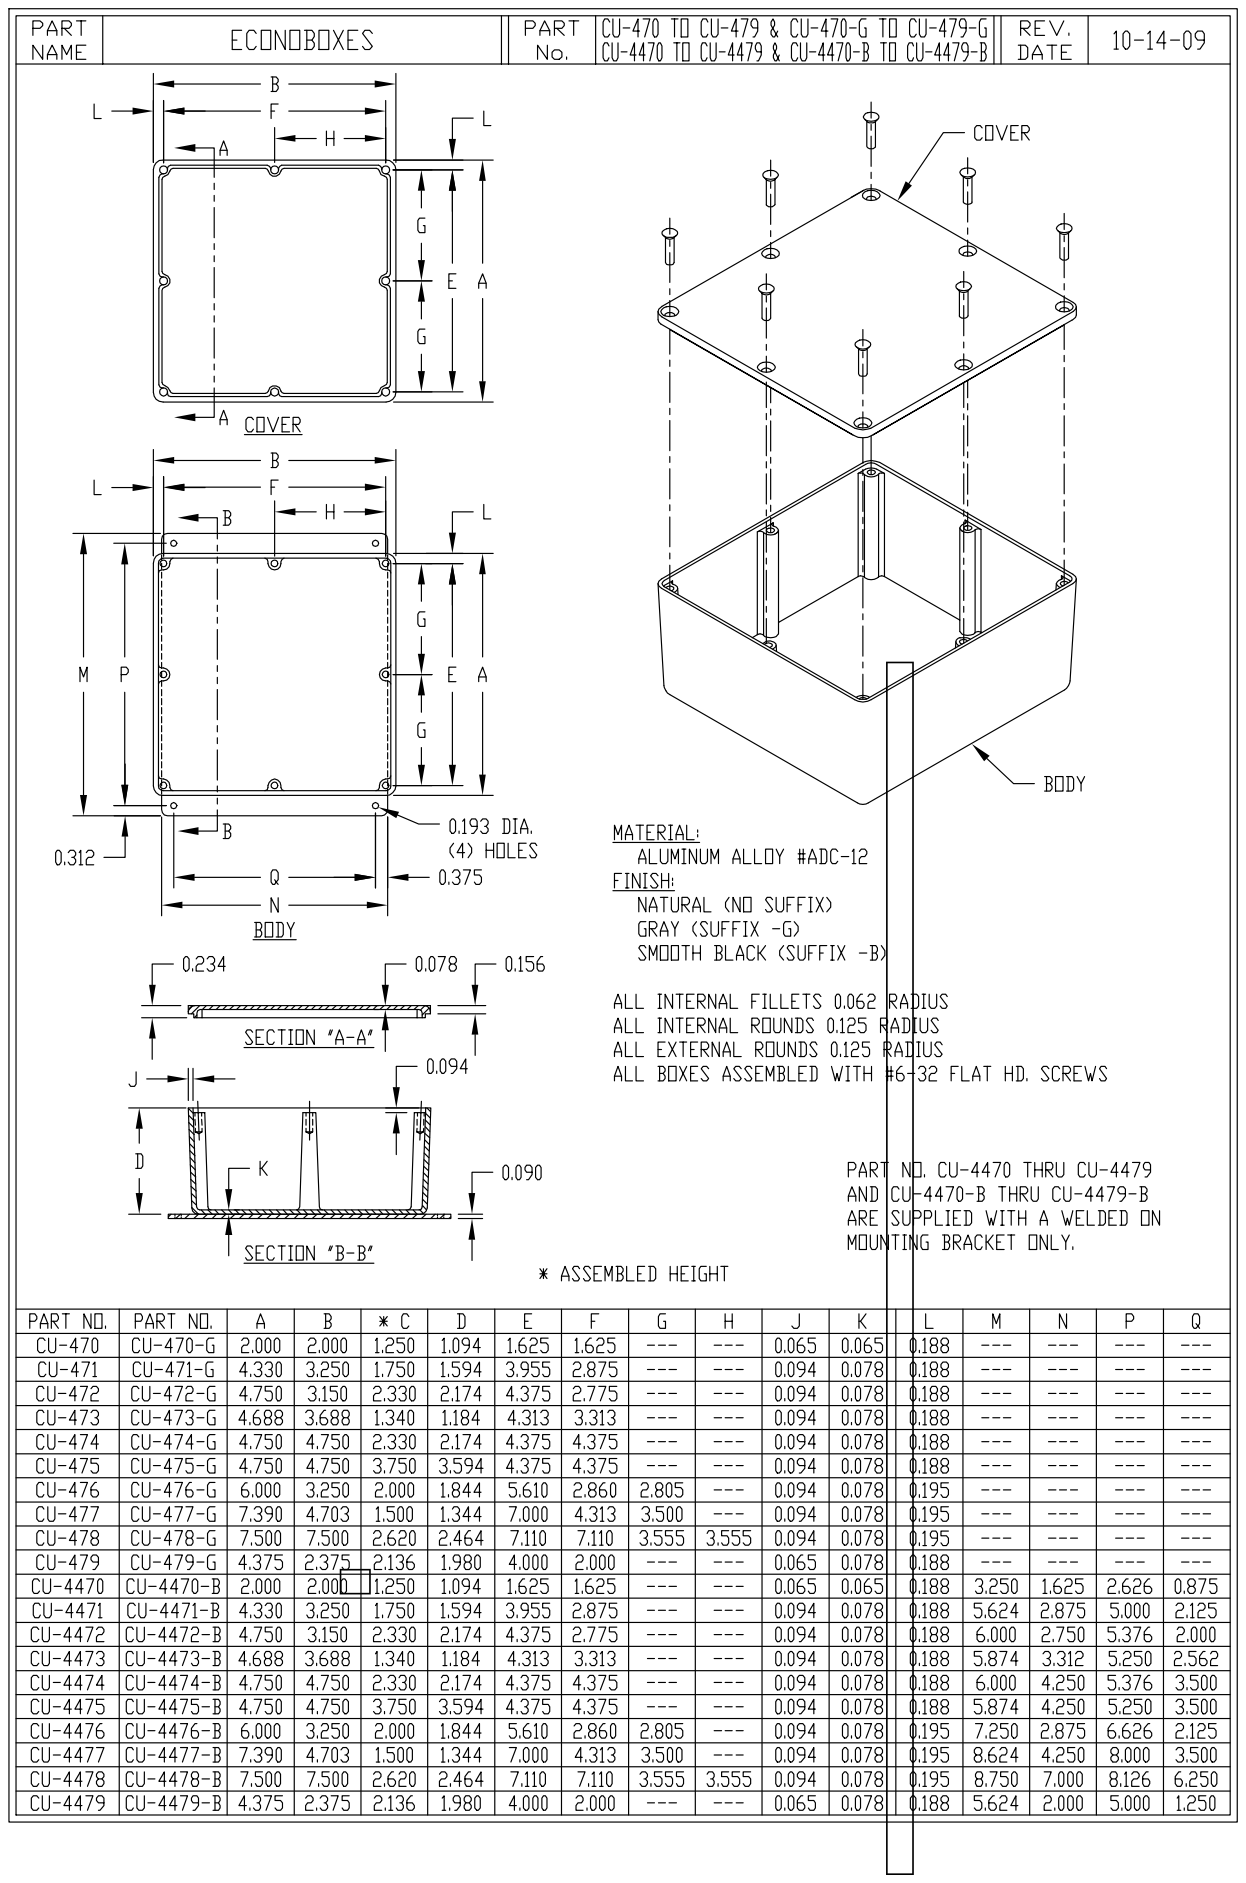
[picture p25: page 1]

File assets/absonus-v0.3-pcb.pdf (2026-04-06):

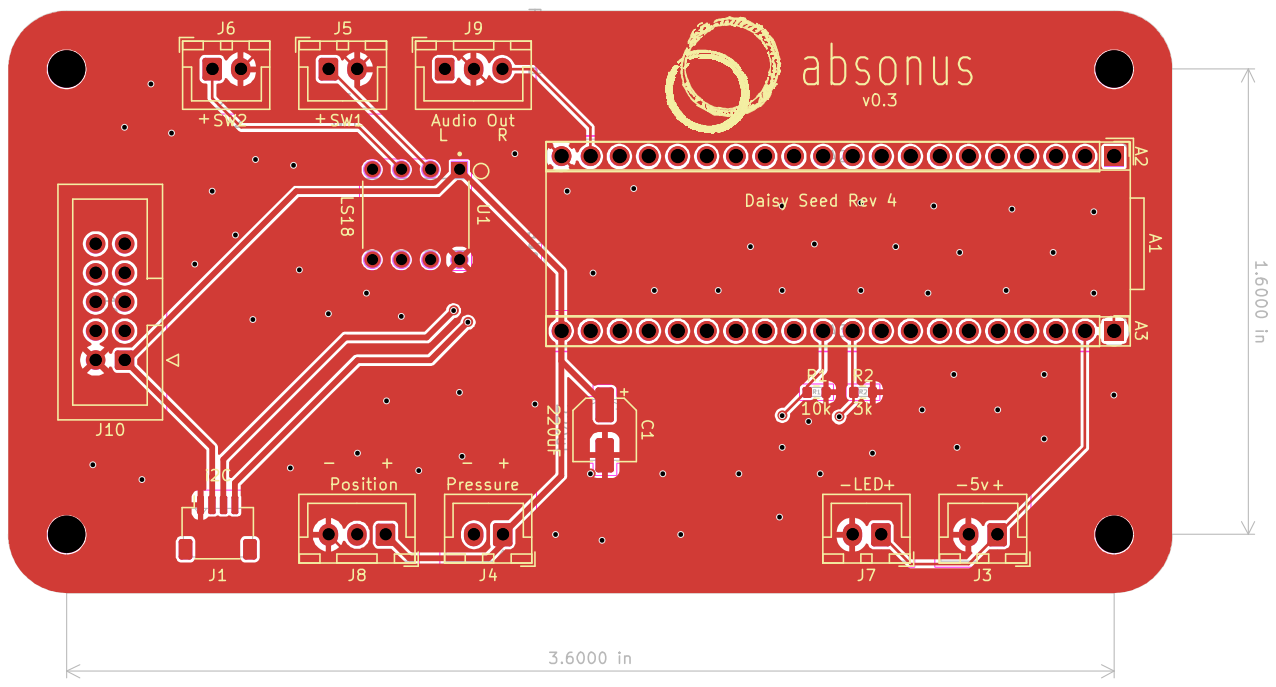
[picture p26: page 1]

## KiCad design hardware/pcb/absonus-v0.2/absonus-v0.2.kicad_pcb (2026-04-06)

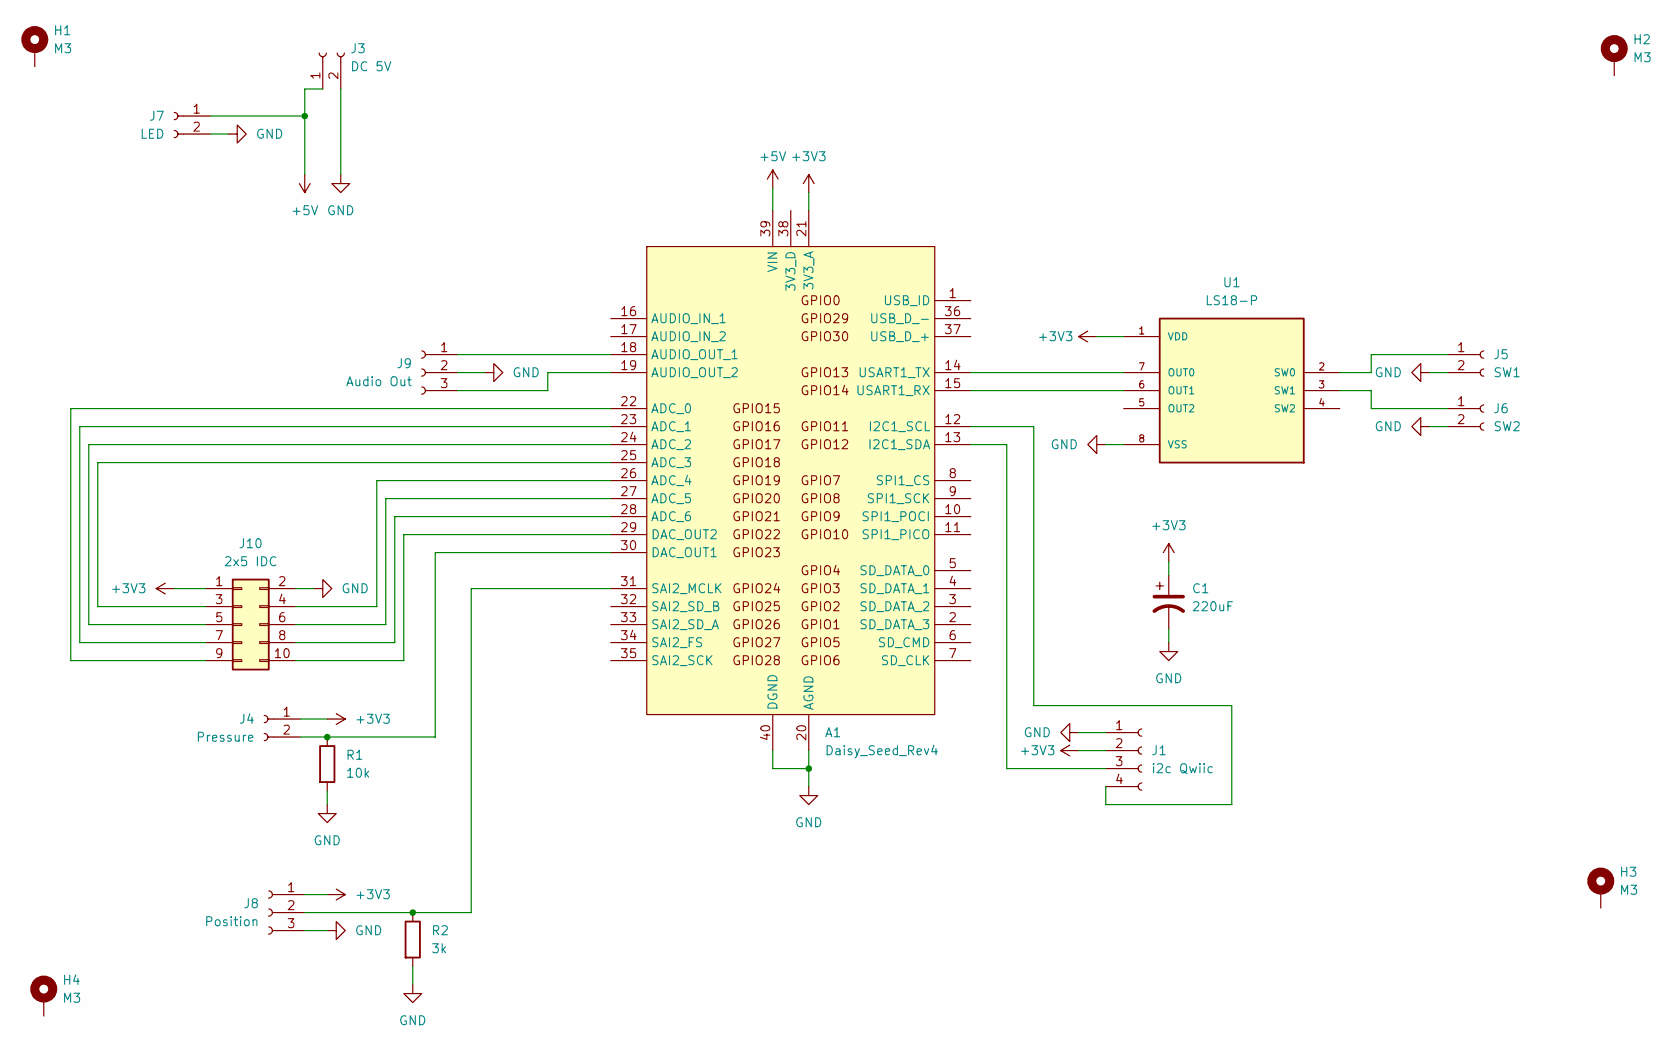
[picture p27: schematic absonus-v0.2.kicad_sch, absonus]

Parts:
A1: Daisy_Seed_Rev4; Electrosmith_Daisy_Seed; LCSC Part # C2897383
C1: 220uF; CP_Elec_5x5.4; LCSC Part # C3337
H1, H2, H3, H4: M3; MountingHole_3.2mm_M3
J1: i2c Qwiic; JST_SH_SM04B-SRSS-TB_1x04-1MP_P1.00mm_Horizontal; LCSC Part # C160404
J3: DC 5V; JST_XH_B2B-XH-A_1x02_P2.50mm_Vertical; LCSC Part # C158012
J4: Pressure; JST_XH_B2B-XH-A_1x02_P2.50mm_Vertical; LCSC Part # C158012
J5: SW1; JST_XH_B2B-XH-A_1x02_P2.50mm_Vertical; LCSC Part # C158012
J6: SW2; JST_XH_B2B-XH-A_1x02_P2.50mm_Vertical; LCSC Part # C158012
J7: LED; JST_XH_B2B-XH-A_1x02_P2.50mm_Vertical; LCSC Part # C158012
J8: Position; JST_XH_B3B-XH-A_1x03_P2.50mm_Vertical; LCSC Part # C144394
J9: Audio Out; JST_XH_B3B-XH-A_1x03_P2.50mm_Vertical; LCSC Part # C144394
J10: 2x5 IDC; IDC-Header_2x05_P2.54mm_Vertical; LCSC Part # C4749194
R1: 10k; R_0603_1608Metric; LCSC Part # C15401
R2: 3k; R_0201_0603Metric; LCSC Part # C4211
U1: LS18-P; DIP787W45P254L927H533Q8; PARTREV March 2023; LCSC Part # C5289485

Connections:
+3V3: A1.21 (3V3_A), C1.1, J1.2, J4.1, J8.1, J10.1, U1.1 (VDD)
+5V: A1.39 (VIN), J3.1, J7.1
GND: A1.20 (AGND), A1.40 (DGND), C1.2, J1.1, J3.2, J5.2, J6.2, J7.2, J8.3, J9.2, J10.2, R1.2, R2.2, U1.8 (VSS)
unnamed: A1.22 (ADC_0), J10.9
unnamed: A1.23 (ADC_1), J10.7
unnamed: A1.24 (ADC_2), J10.5
unnamed: A1.25 (ADC_3), J10.3
unnamed: A1.26 (ADC_4), J10.4
unnamed: A1.27 (ADC_5), J10.6
unnamed: A1.28 (ADC_6), J10.8
unnamed: A1.18 (AUDIO_OUT_1), J9.1
unnamed: A1.19 (AUDIO_OUT_2), J9.3
unnamed: A1.30 (DAC_OUT1), J4.2, R1.1
unnamed: A1.29 (DAC_OUT2), J10.10
unnamed: A1.12 (I2C1_SCL), J1.4
unnamed: A1.13 (I2C1_SDA), J1.3
unnamed: A1.31 (SAI2_MCLK), J8.2, R2.1
unnamed: A1.15 (USART1_RX), U1.6 (OUT1)
unnamed: A1.14 (USART1_TX), U1.7 (OUT0)
unnamed: J5.1, U1.2 (SW0)
unnamed: J6.1, U1.3 (SW1)

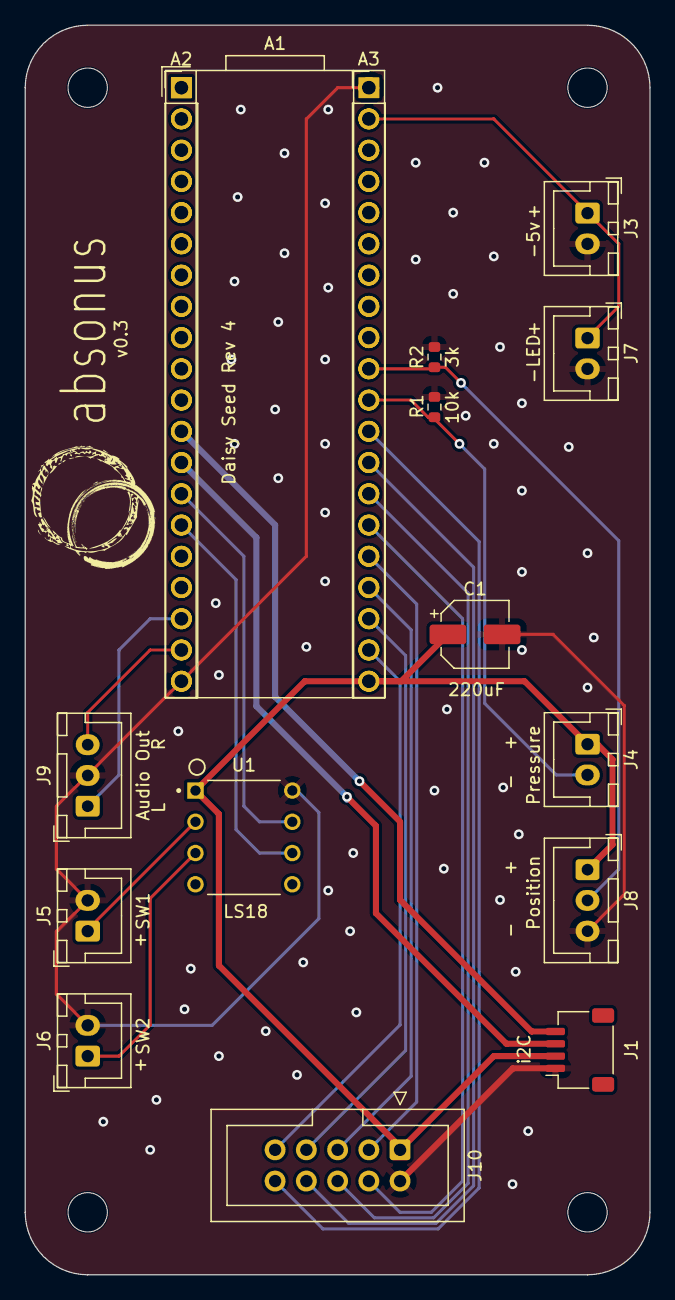
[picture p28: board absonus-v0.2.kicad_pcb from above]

Board: 2 copper layers, 50.8 x 101.6 mm, 20 parts (0 on the bottom side), 21 nets.

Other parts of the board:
A2, A3: PinHeader_1x20_P2.54mm_Vertical

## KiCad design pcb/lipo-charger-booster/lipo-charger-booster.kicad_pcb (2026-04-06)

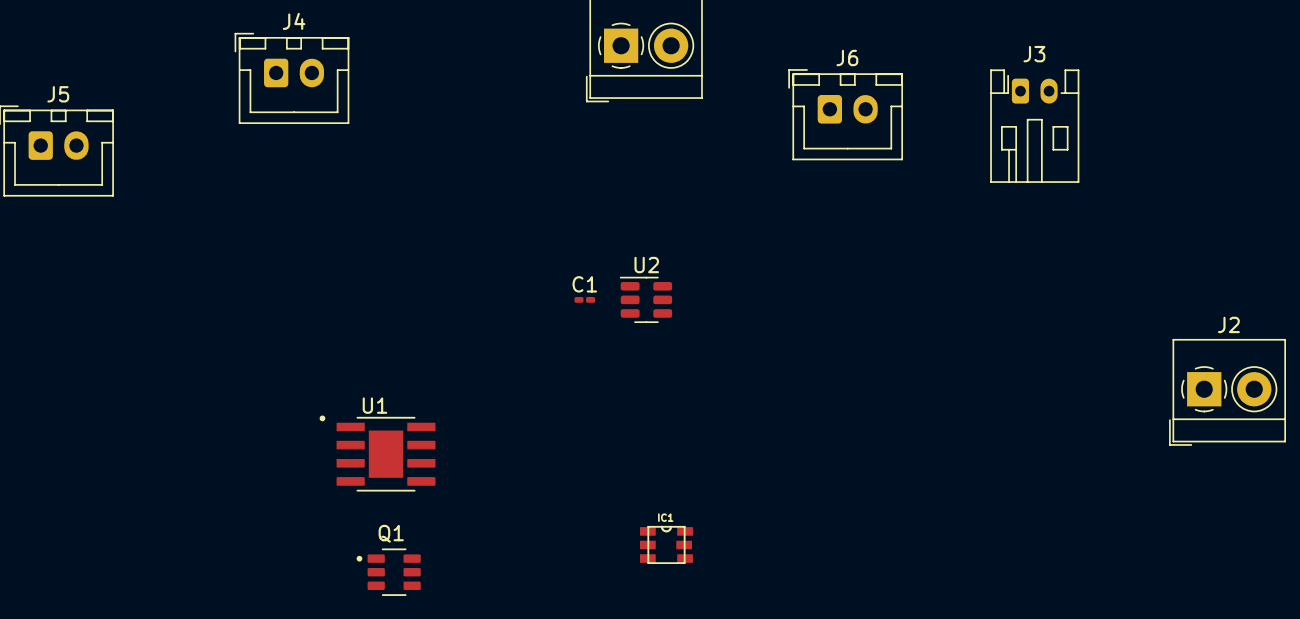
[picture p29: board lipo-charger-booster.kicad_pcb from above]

Board: 2 copper layers, 11 parts (0 on the bottom side), 8 nets, no tracks yet.

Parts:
C1: 10uF; C_0201_0603Metric_Pad0.64x0.40mm_HandSolder
IC1: FS312F-G; SOT23-6
J1: 5v IN; TerminalBlock_4Ucon_1x02_P3.50mm_Horizontal
J2: 5v OUT; TerminalBlock_4Ucon_1x02_P3.50mm_Horizontal
J3: Battery; JST_PH_S2B-PH-K_1x02_P2.00mm_Horizontal
J4: RED LED; JST_XH_B2B-XH-A_1x02_P2.50mm_Vertical
J5: GREEN LED; JST_XH_B2B-XH-A_1x02_P2.50mm_Vertical
J6: Switch; JST_XH_B2B-XH-A_1x02_P2.50mm_Vertical
Q1: FS8205; SOT95P280X145-6N
U1: TP4056; SOP127P600X175-9N
U2: MT3608; SOT-23-6

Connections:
+BATT: J3.1, J6.1, U1.5 (BAT)
-BATT: IC1.6 (GND), J3.2, Q1.3
GND: C1.2, J1.2, J2.2, Q1.1, U1.1 (TEMP), U1.3 (GND), U2.2 (GND)
unnamed: IC1.3 (OC), Q1.6
unnamed: IC1.1 (OD), Q1.4
unnamed: J6.2, U2.4 (EN), U2.5 (IN)
unnamed: Q1.2, Q1.5
VCC: C1.1, J1.1, J4.1, J5.1, U1.4 (VCC), U1.8 (CE)

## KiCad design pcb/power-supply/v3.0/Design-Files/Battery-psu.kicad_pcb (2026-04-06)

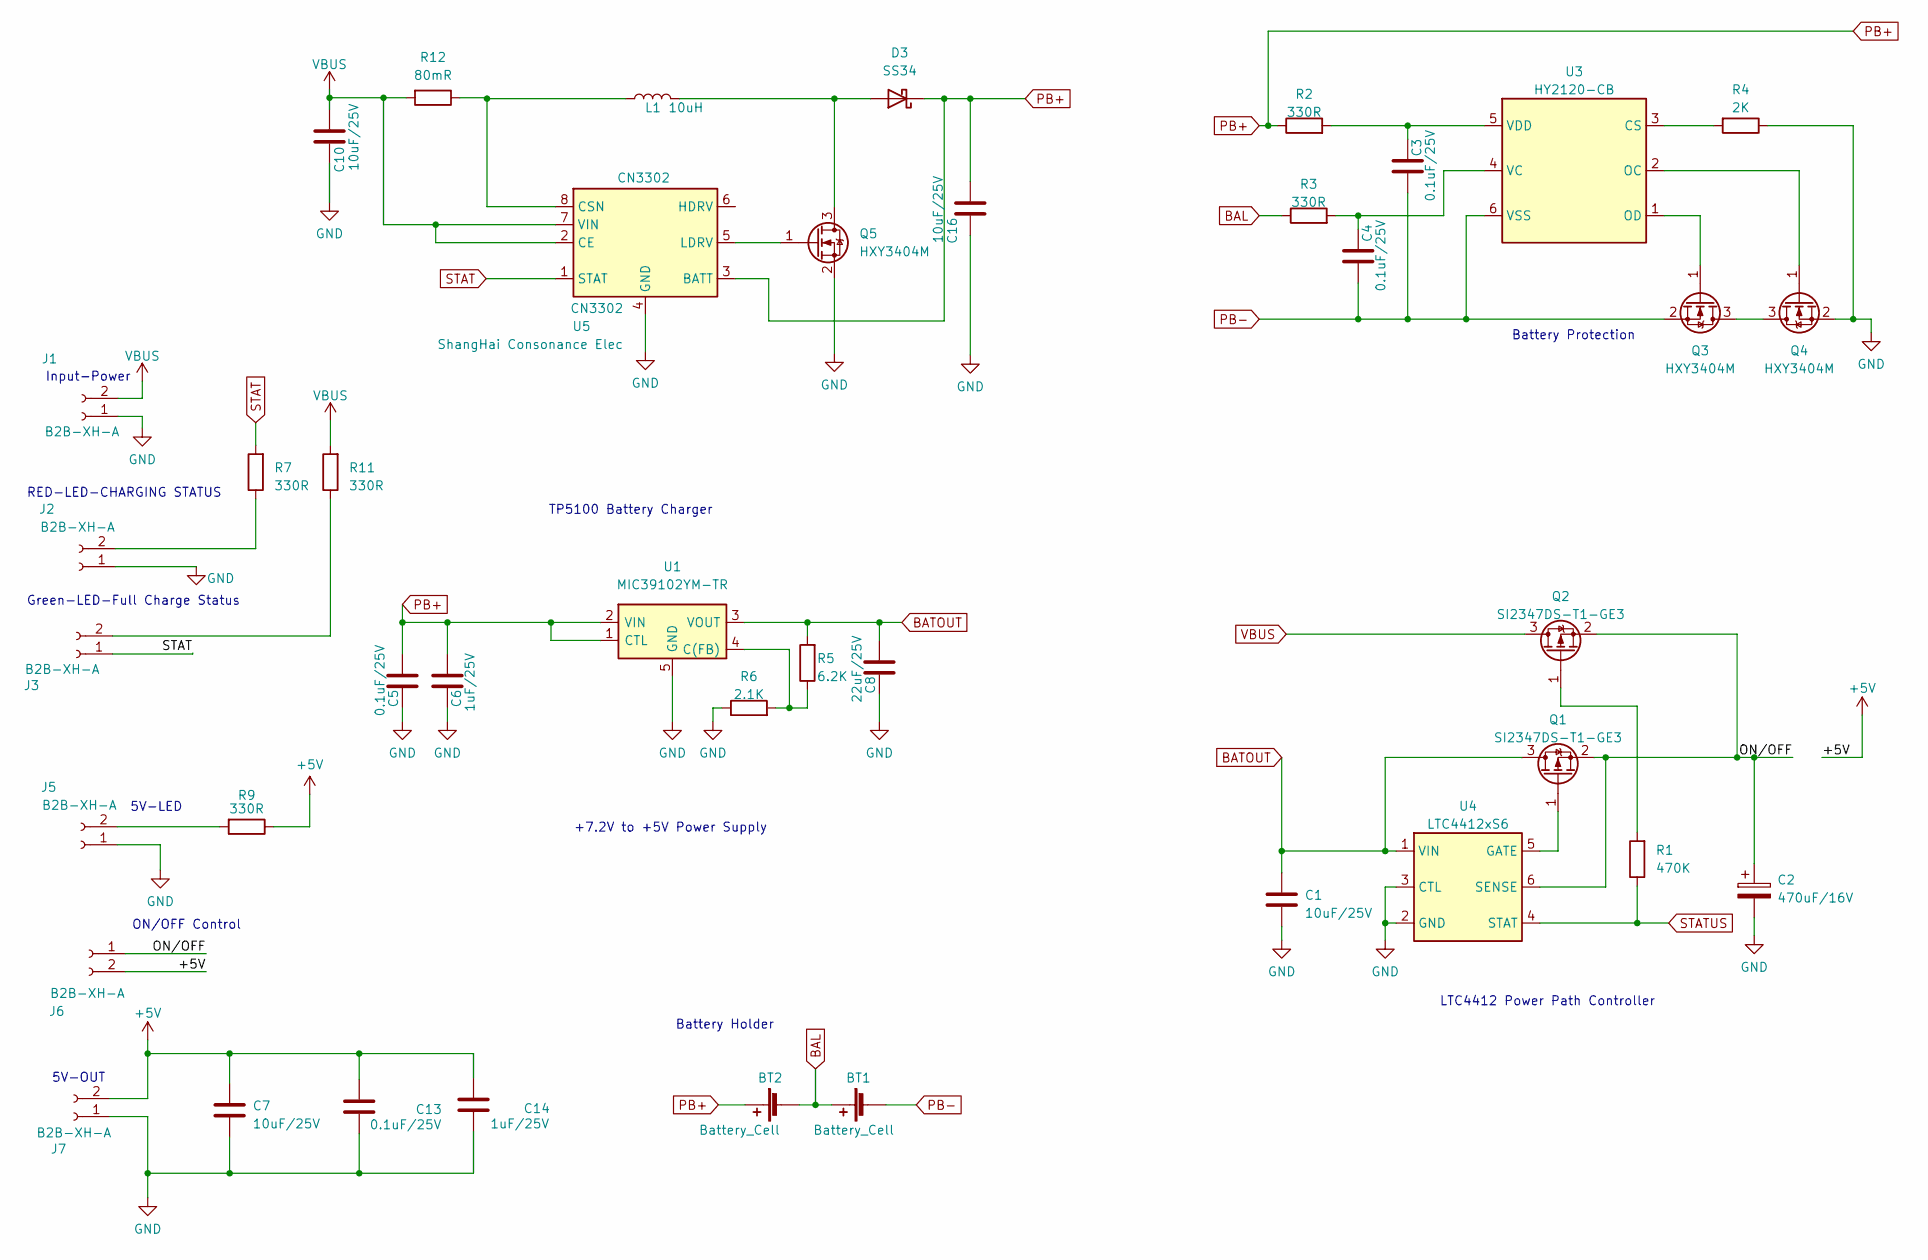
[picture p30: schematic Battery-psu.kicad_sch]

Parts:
BT1: Battery_Cell; BatteryHolder_MPD_BH-18650-PC2; LCSC-PN C19184083
BT2: Battery_Cell; BatteryHolder_MPD_BH-18650-PC2; LCSC PN C19184083
C1, C7, C10, C16: 10uF/25V; C_0603_1608Metric; LCSC PN C96446
C2: 470uF/16V; CP_Elec_6.3x7.7; LCSC PN C87858
C3, C4, C5, C13: 0.1uF/25V; C_0603_1608Metric; LCSC PN C83054
C6, C14: 1uF/25V; C_0603_1608Metric; LCSC PN C2857985
C8: 22uF/25V; C_0603_1608Metric; LCSC PN C602037
D3: SS34; D_SMA; LCSC PN C3011102
J1, J2, J3, J5, J6, J7: B2B-XH-A; JST_XH_B2B-XH-A_1x02_P2.50mm_Vertical; LCSC PN C158012
L1: 10uH; L_Wuerth_HCI-1040; LCSC PN C182194
Q1, Q2: SI2347DS-T1-GE3; SOT-23; LCSC PN C145002
Q3, Q4, Q5: HXY3404M; SOT-23; LCSC PN C2926128
R1: 470K; R_0603_1608Metric; LCSC PN C2907171
R2, R3, R7, R9, R11: 330R; R_0603_1608Metric; LCSC PN C2907152
R4: 2K; R_0603_1608Metric; LCSC PN C2907137
R5: 6.2K; R_0603_1608Metric; LCSC PN C2907054
R6: 2.1K; R_0603_1608Metric; LCSC PN C2907137
R12: 80mR; R_2512_6332Metric; LCSC PN C421509
U1: MIC39102YM-TR; SOIC-8_3.9x4.9mm_P1.27mm; LCSC PN C627993
U3: HY2120-CB; SOT-23-6; LCSC PN C116509
U4: LTC4412xS6; TSOT-23-6; LCSC PN C514442
U5: CN3302; SOIC-8_3.9x4.9mm_P1.27mm; LCSC PN C559039

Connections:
+5V: C7.1, C13.1, C14.1, J6.2, J7.2, R9.1
/ON/OFF: C2.1, J6.1, Q1.2 (S), Q2.2 (S), U4.6 (SENSE)
BAL: BT1.1 (+), BT2.2 (-), R3.1
BATOUT: C1.1, C8.1, Q1.3 (D), R5.2, U1.3 (VOUT), U4.1 (VIN)
GND: C1.2, C2.2, C5.2, C6.2, C7.2, C8.2, C10.2, C13.2, C14.2, C16.2, J1.1, J2.1, J5.1, J7.1, Q4.2 (S), Q5.2 (S), R4.1, R6.1, U1.5 (GND), U1.6 (GND), U1.7 (GND), U1.8 (GND), U4.2 (GND), U4.3 (CTL), U5.4 (GND)
unnamed: D3.2 (A), L1.2, Q5.3 (D)
unnamed: J2.2, R7.1
unnamed: J3.2, R11.1
unnamed: J5.2, R9.2
unnamed: Q1.1 (G), U4.5 (GATE)
unnamed: Q2.1 (G), R1.2
unnamed: Q3.3 (D), Q4.3 (D)
unnamed: Q3.1 (G), U3.1 (OD)
unnamed: Q4.1 (G), U3.2 (OC)
unnamed: Q5.1 (G), U5.5 (LDRV)
unnamed: R5.1, R6.2, U1.4 (C(FB))
unnamed: R4.2, U3.3 (CS)
unnamed: C4.1, R3.2, U3.4 (VC)
unnamed: C3.1, R2.2, U3.5 (VDD)
unnamed: L1.1, R12.1, U5.8 (CSN)
PB+: BT2.1 (+), C5.1, C6.1, C16.1, D3.1 (K), R2.1, U1.1 (CTL), U1.2 (VIN), U5.3 (BATT)
PB-: BT1.2 (-), C3.2, C4.2, Q3.2 (S), U3.6 (VSS)
STAT: J3.1, R7.2, U5.1 (STAT)
STATUS: R1.1, U4.4 (STAT)
VBUS: C10.1, J1.2, Q2.3 (D), R11.2, R12.2, U5.2 (CE), U5.7 (VIN)

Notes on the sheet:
ON/OFF Control
Battery Holder
5V-LED
+7.2V to +5V Power Supply
5V-OUT
LTC4412 Power Path Controller
RED-LED-CHARGING STATUS
Battery Protection
TP5100 Battery Charger
Green-LED-Full Charge Status
Input-Power

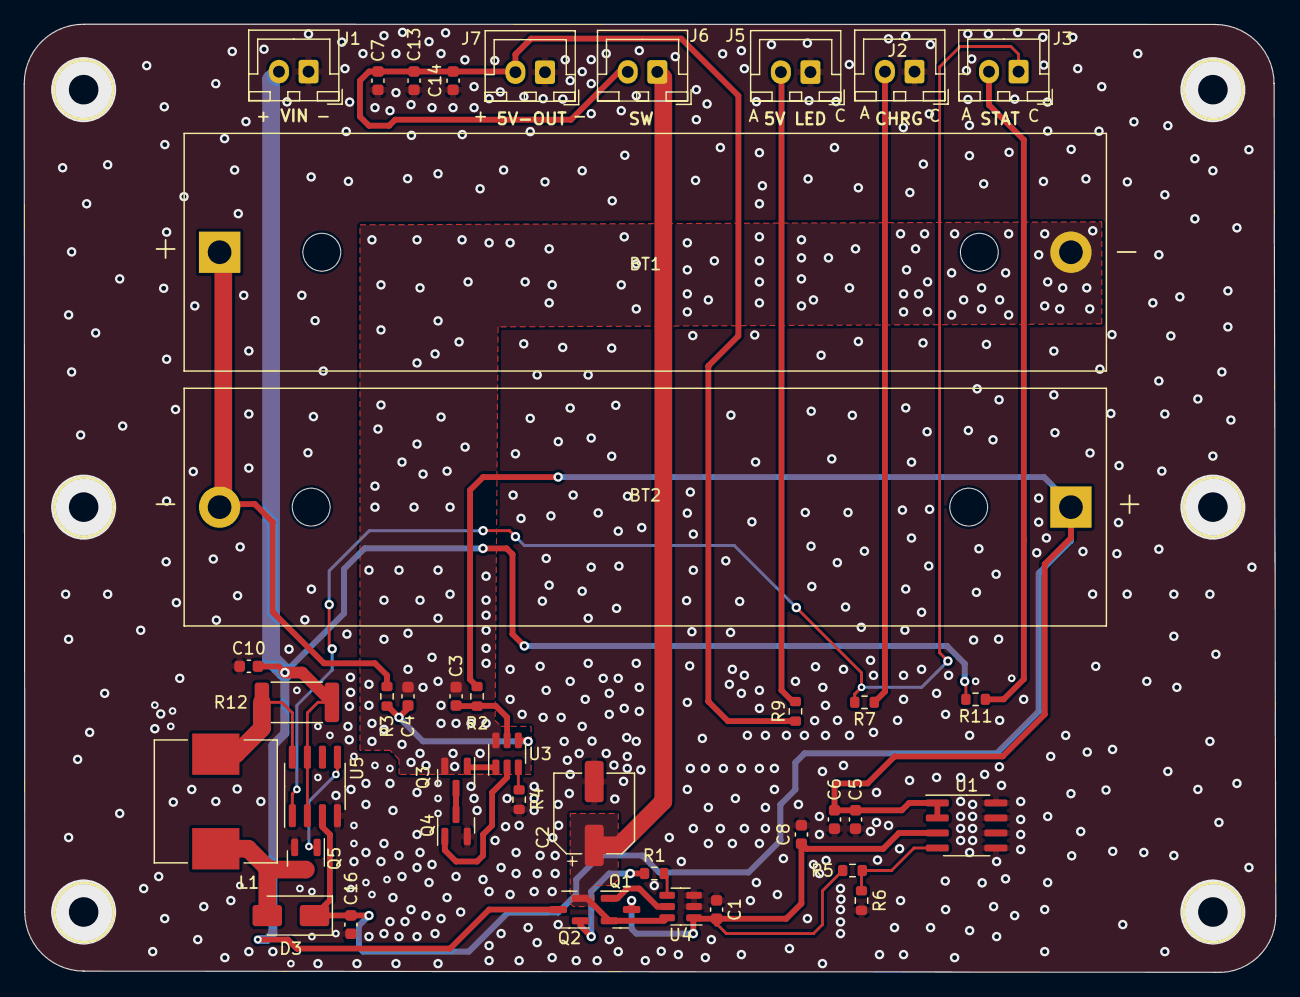
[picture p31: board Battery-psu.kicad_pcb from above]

Board: 2 copper layers, 105.8 x 80.2 mm, 41 parts (0 on the bottom side), 25 nets.

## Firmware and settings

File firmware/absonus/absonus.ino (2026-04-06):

#include "DaisyDuino.h"
#include "math.h"
#include "fmchorus.h"
#include "cubicnl.h"
#include "tremor.h"

using namespace idfk;

/* Hardware Setup */
DaisyHardware hw;
size_t numChannels;

/* Debugging Settings */
const bool kDebug = false;


/* Analog Reading Settings */
const int kAdcBits = 12;
const long kAdcMax = 4095;

/* Fequency Range: A1-A7 */
const float kCarrierFrequencyLow = 55.0;
const float kCarrierFrequencyHigh = 3520.0;

/* Pin Mappings */
const int kModulationDepthPin = A6;
const int kDistortionLevelPin = A0;
const int kChorusDepthPin = A7;
const int kTremoloSpeedPin = D13;
const int kTremoloOnPin = D14;

const int kFilterFreqPin = A1;
const int kFilterResonancePin = A5;
const int kNoiseLevelPin = A2;
const int kReverbLevelPin = A4;
const int kVolumePin = A3;

const int kForceSensorPin = A8;
const int kSoftPotPin = A9;

/* Sensor calibration settings for lower threshold */
const long kForceSensorThreshold = 20;
const float kGateThreshhold = 0.1;
const long kSoftPotThreshold = 44;

/* Envelope, Gain, Volume */
static Adsr envelope;

static Port gainPortamento;
static bool gate = false;
static long gainReading;
static float gain;

static long volumeReading;
static Port volumePortamento;
static float volumeLevel;

/* FM Synthesis Section */
static FmChorus fmOsc;
static Port carrierPortamento;
static float carrierScalar;
static float carrierFreq;
static long carrierFreqReading;
static float previousCarrierFreq;

static long modulatorDepthReading;
static Port modulatorDepthPortamento;
static float modulatorDepth;

static long modulatorRatioReading;
static Port modulatorRatioPortamento;
static float modulatorRatio;

static Port chorusDepthPortamento;
static long chorusDepthReading;
static float chorusDepth;

/* Tremolo Settings */
static Tremor tremolo;
static Port tremoloDepthPortamento;
static float tremoloDepth;
static Port tremoloWidthPortamento;
static float tremoloWidth;
static Port tremoloFreqPortamento;
static float tremoloFreq;
static int tremoloSpeedReading;
static int tremoloOnReading;
static boolean tremoloOn;
static float tremoloScalar;

const float kTremoloFreqLow = 1.0f;
const float kTremoloDepthLow = 0.5f;
const float kTremoloWidthLow = 0.66;

const float kTremoloFreqHigh = 13.0f;
const float kTremoloDepthHigh = 0.75f;
const float kTremoloWidthHigh = 0.83f;

/* Distortion Settings */
static Cubicnl distortion;
static long distortionLevelReading;
static Port distortionLevelPortamento;
static float distortionLevel;

/* Filter Settings */
static MoogLadder filter;
static float filterFreq;
static long filterFreqReading;
static Port filterFreqPortamento;
static float filterRes;
static long filterResReading;
static Port filterResPortamento;
static float filterScalar;

const float kFilterFreqLow = 20.0f;
const float kFilterFreqHigh = 24000.0f;

/* Reverb Settings */
static ReverbSc reverb;
static Port reverbLevelPortamento;
static float reverbLevel;
static long reverbLevelReading;
static CrossFade crossfadel, crossfader;

/* Noise Settings */
static WhiteNoise noise;
static Port noiseLevelPortamento;
static float noiseLevel;
static long noiseLevelReading;



void MyCallback(float **in, float **out, size_t size) 
{
  float slewedVolumeLevel, slewedGain; 
  float envelopeOut, sig, sigl, sigr;
  float slewedCarrierFreq, slewedModulatorDepth, slewedModulatorRatio, slewedChorusDepth;
  float slewedDistortionLevel;
  float slewedTremoloFreq, slewedTremoloDepth, slewedTremoloWidth;
  float trem, treml, tremr;
  float slewedReverbLevel;
  float slewedNoiseLevel;

  for (size_t i = 0; i < size; i++) 
  {
    envelopeOut = envelope.Process(gate);
    slewedVolumeLevel = volumePortamento.Process(volumeLevel);
    slewedGain = gainPortamento.Process(gain);

    if(gate == true) 
    {
      previousCarrierFreq = carrierFreq;
      slewedCarrierFreq = carrierPortamento.Process(carrierFreq);
      previousCarrierFreq = slewedCarrierFreq;
    }
    else 
    {
      // Retain previousCarrierFreq on Note Off to prevent fall off to kCarrierFrequencyLow
      slewedCarrierFreq = carrierPortamento.Process(previousCarrierFreq);
    }

    //slewedModulatorRatio = modulatorRatioPortamento.Process(modulatorRatio);
    slewedModulatorDepth = modulatorDepthPortamento.Process(modulatorDepth);

    slewedChorusDepth = chorusDepthPortamento.Process(chorusDepth);

    fmOsc.SetAmp(envelopeOut * slewedGain);
    //fmOsc.SetRatio(slewedModulatorRatio);  // switched to fixed ratio
    fmOsc.SetRatio(1.414214);
    fmOsc.SetDepth(slewedModulatorDepth);
    fmOsc.SetFreq(slewedCarrierFreq);
    fmOsc.SetWidth(slewedChorusDepth);
    sig = fmOsc.Process();
    
    slewedNoiseLevel = noiseLevelPortamento.Process(noiseLevel);
    noise.SetAmp(slewedNoiseLevel);
    sig = sig + noise.Process() * 0.5 * slewedGain;

    slewedDistortionLevel = distortionLevelPortamento.Process(distortionLevel);
    distortion.SetDrive(slewedDistortionLevel);
    sig = distortion.Process(sig);

    filter.SetRes(filterRes);
    filter.SetFreq(filterFreq);
    sig = filter.Process(sig);

    slewedTremoloFreq = tremoloFreqPortamento.Process(tremoloFreq);
    slewedTremoloDepth = tremoloDepthPortamento.Process(tremoloDepth);
    slewedTremoloWidth = tremoloWidthPortamento.Process(tremoloWidth);
    tremolo.SetFreq(slewedTremoloFreq);
    tremolo.SetDepth(slewedTremoloDepth);
    tremolo.SetWidth(slewedTremoloWidth);

    trem = tremolo.Process();
    treml = tremolo.GetLeft();
    tremr = tremolo.GetRight();

    sig = sig * trem;
    sigl = sig * treml;
    sigr = sig * tremr;

    slewedReverbLevel = reverbLevelPortamento.Process(reverbLevel);
    reverb.SetFeedback(slewedReverbLevel);
    float outl, outr;
    reverb.Process(sigl, sigr, &outl, &outr);

    crossfadel.SetPos(slewedReverbLevel);
    crossfader.SetPos(slewedReverbLevel);

    sigl = crossfadel.Process(sigl, outl);
    sigr = crossfadel.Process(sigr, outr);
    //sigl = sigl * (1 - slewedReverbLevel) + outl * slewedReverbLevel;
    //sigr = sigr * (1 - slewedReverbLevel) + outr * slewedReverbLevel;

    out[0][i] = sigl * slewedVolumeLevel;
    out[1][i] = sigr * slewedVolumeLevel;
  } // end for loop
} // End MyCallback(float **in, float **out, size_t size)


float normalizeSoftpot(long sensorValue) 
{
  long value;
  float normalizedValue;
  value = constrain(sensorValue, kSoftPotThreshold, kAdcMax);
  value = map(value, kSoftPotThreshold, kAdcMax, 0, kAdcMax);
  normalizedValue = (float)value/(float)kAdcMax;
  //return 1.0f - normalizedValue;
  return normalizedValue;
} // End normalizeSoftpot(long sensorValue)


float normalizeForceSensor(long sensorValue) 
{
  long value;
  float normalizedValue;
  value = constrain(sensorValue, kForceSensorThreshold, kAdcMax);
  value = map(value, kForceSensorThreshold, kAdcMax, 0, kAdcMax);
  normalizedValue = (float) value / (float) kAdcMax;
  if (normalizedValue > kGateThreshhold) {
    gate = true;
  }
  else {
    gate = false;
    //Serial.println("Gate Off");
  }
  return normalizedValue;
} // End normalizeForceSensor(long sensorValue)


void setup() {
  float sampleRate;
  /* harware initialization */
  hw = DAISY.init(DAISY_SEED, AUDIO_SR_48K);
  numChannels = hw.num_channels;
  sampleRate = DAISY.get_samplerate();

  analogReadResolution(kAdcBits);
  pinMode(kTremoloSpeedPin, INPUT);
  pinMode(kTremoloOnPin, INPUT);

  if(kDebug)
  {
    Serial.begin(9600);
  }

  /* FM Sythesis Initialization */
  carrierScalar = log2(kCarrierFrequencyHigh / kCarrierFrequencyLow);
  modulatorRatio = 1.0f;
  modulatorDepth = 0.0f;
  chorusDepth = 0.0f;

  fmOsc.Init(sampleRate);
  fmOsc.SetFreq(kCarrierFrequencyLow);
  fmOsc.SetCarrierWaveform(Oscillator::WAVE_SAW);
  fmOsc.SetModulatorWaveform(Oscillator::WAVE_TRI);

  fmOsc.SetRatio(modulatorRatio);
  fmOsc.SetDepth(modulatorDepth);
  fmOsc.SetAmp(gain);
  
  carrierPortamento.Init(sampleRate, 0.01f);
  modulatorDepthPortamento.Init(sampleRate, 0.01);
  //modulatorRatioPortamento.Init(sampleRate, 0.01);
  chorusDepthPortamento.Init(sampleRate, 0.01);

  /* Envelope, Gain and Volume Initialization */
  gate = false;
  gain = 0.0f;

  envelope.Init(sampleRate);
  envelope.SetTime(ADSR_SEG_ATTACK,0.1);
  envelope.SetTime(ADSR_SEG_DECAY, 0.1);
  envelope.SetTime(ADSR_SEG_RELEASE, 0.01);
  envelope.SetSustainLevel(0.7);
  gainPortamento.Init(sampleRate, 0.01);
  volumePortamento.Init(sampleRate, 0.01);

  /* Tremolo Intialization */
  tremoloFreq = 0.0f;
  tremoloOn = false;
  tremoloScalar = log2(kTremoloFreqHigh / kTremoloFreqLow);  // TODO: Ensure this is better than linear scaling
  tremolo.Init(sampleRate);
  tremolo.SetDepth(0.5f);
  tremolo.SetFreq(kTremoloFreqLow);
  tremolo.SetWidth(0.5f);
  tremoloFreqPortamento.Init(sampleRate, 4.0f);
  tremoloDepthPortamento.Init(sampleRate, 5.0f);
  tremoloWidthPortamento.Init(sampleRate, 5.0f);

  /* Distortion Initialization */
  distortionLevelPortamento.Init(sampleRate, 0.01);
  distortion.Init(sampleRate);
  distortion.SetDrive(0.0f);
  distortion.SetOffset(0.0f);

  /* Filter Initialization */
  filter.Init(sampleRate);
  filter.SetRes(0.0f);
  filterFreqPortamento.Init(sampleRate, 0.01);
  filterResPortamento.Init(sampleRate, 0.01);
  filterFreq = kFilterFreqHigh;
  filterRes = 0.0f;
  filterScalar = log2(kFilterFreqHigh / kFilterFreqLow);

  /* Reverb Initialization */
  reverb.Init(sampleRate);
  reverb.SetFeedback(0.0f);
  reverb.SetLpFreq(18000.0f);
  reverbLevelPortamento.Init(sampleRate, 0.01);

  crossfadel.Init();
  crossfadel.SetCurve(CROSSFADE_CPOW);
  crossfader.Init();
  crossfader.SetCurve(CROSSFADE_CPOW);

  /* Noise Initialization */
  noise.Init();
  noise.SetAmp(0.0f);
  noiseLevelPortamento.Init(sampleRate, 0.01);

  DAISY.begin(MyCallback);
}  // End setup()


void loop() {
  unsigned long lastPrintTime = 0;
  unsigned long now;

  /* Oscillator Gain and Volume */
  volumeReading = analogRead(kVolumePin);
  volumeLevel = volumeReading / (float) kAdcMax;

  gainReading = analogRead(kForceSensorPin);
  gain = normalizeForceSensor(gainReading);

  carrierFreqReading = analogRead(kSoftPotPin);
  carrierFreq = pow(2.0, normalizeSoftpot(carrierFreqReading) * carrierScalar) * kCarrierFrequencyLow;

  modulatorDepthReading = analogRead(kModulationDepthPin);
  modulatorDepth = modulatorDepthReading  / (float) kAdcMax;

  //modulatorRatioReading = analogRead(kModulationRatioPin); 
  //modulatorRatio = (modulatorRatioReading / (float) kAdcMax) + 1.0f;

  chorusDepthReading = analogRead(kChorusDepthPin);
  chorusDepth = (chorusDepthReading / (float) kAdcMax);

  /* Tremolo Readings - 2 switch controls */
  tremoloOnReading = digitalRead(kTremoloOnPin);
  tremoloSpeedReading = digitalRead(kTremoloSpeedPin);
  if(tremoloOnReading > 0)
  {
    tremoloOn = false;
    tremoloFreq = 0.0f;
    tremoloDepth = 0.0f;
    tremoloWidth = 0.0f;
  }
  else
  {
    tremoloOn = true;
    if(tremoloSpeedReading > 0)
    {
      tremoloFreq = kTremoloFreqLow;
      tremoloDepth = kTremoloDepthLow;
      tremoloWidth = kTremoloWidthLow;
    }
    else
    {
      tremoloFreq = kTremoloFreqHigh;
      tremoloDepth = kTremoloDepthHigh;
      tremoloWidth = kTremoloWidthHigh;
    }
  }

  /* Distortion Reading */
  distortionLevelReading = analogRead(kDistortionLevelPin);
  distortionLevel = (distortionLevelReading / (float) kAdcMax);


/* Filter Readings */

  filterFreqReading = analogRead(kFilterFreqPin);
  filterFreq = pow(2.0, (filterFreqReading / (float) kAdcMax) * filterScalar) * kFilterFreqLow;
  
  filterResReading = analogRead(kFilterResonancePin);
  filterRes = (filterResReading / (float) kAdcMax);

/* Reverb Readings */
  reverbLevelReading = analogRead(kReverbLevelPin);
  reverbLevel = reverbLevelReading / (float) kAdcMax;

  /* Noise Reading */
  noiseLevelReading = analogRead(kNoiseLevelPin);
  noiseLevel = noiseLevelReading / (float) kAdcMax;

  if(kDebug)
  {
    now = millis();
    if((now - lastPrintTime > 100))
    {
      lastPrintTime = now;
      Serial.print("modulatorDepth:");
      Serial.print(modulatorDepth);
      Serial.print(",");

      Serial.print("distortionLevel:");
      Serial.print(distortionLevel);
      Serial.print(",");

      Serial.print("chorusDepth:");
      Serial.print(chorusDepth);
      Serial.print(",");

      Serial.print("tremoloSpeedReading:");
      Serial.print(tremoloSpeedReading);
      Serial.print(",");
      
      Serial.print("tremoloOnReading:");
      Serial.print(tremoloOnReading);
      Serial.print(",");

      Serial.print("filterFreq:");
      Serial.print(filterFreq);
      Serial.print(",");

      Serial.print("filterRes:");
      Serial.print(filterRes);
      Serial.print(",");
      
      Serial.print("noiseLevel:");
      Serial.print(noiseLevel);
      Serial.print(",");

      Serial.print("reverbLevel:");
      Serial.print(reverbLevel);
      Serial.print(",");

      Serial.print("volumeLevel:");
      Serial.print(volumeLevel);
      Serial.print(",");

      Serial.print("carrierFreq:");
      Serial.print(carrierFreq);
      Serial.print(",");
      
      Serial.print("gain:");
      Serial.print(gain);
      Serial.println("");

    }
  }

} // End loop()

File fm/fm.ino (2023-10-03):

#include "DaisyDuino.h"
#include "math.h"
#include "fm.h"
#include "cubicnl.h"
#include "tremor.h"

using namespace idfk;

const int kAdcBits = 12;
const long kAdcMax = 4095;

// A1 - A7
const float kCarrierFrequencyLow = 55.0;
const float kCarrierFrequencyHigh = 3520.0;

const int kModulationDepthPin = A9;
const int kModulationRatioPin = A0;
const int kVolumePin = A1;
const int kForceSensorPin = A4;
const int kSoftPotPin = A5;
const int kDistortionLevelPin = A3;
const int kChorusDepthPin = A8;
/* -- original ports - hijacking for testing tremolo
const int kNoiseLevelPin = A6;
const int kFilterCutOffPin = A2;
const int kFilterResonancePin = A7;
*/
const int kTremoloFreqPin = A6;
const int kTremoloDepthPin = A2;
const int kTremoloWidthPin = A7;


/* Sensor calibration settings for lower threshold */
const long kForceSensorThreshold = 20;
const float kGateThreshhold = 0.1;
const long kSoftPotThreshold = 44;

/* Envelope, Gain, Volume */
static Adsr envelope;

static Port gainPortamento;
static bool gate = false;
static long gainReading;
static float gain;

static long volumeReading;
static Port volumePortamento;
static float volumeLevel;

static Fm fmOsc;
static Port carrierPortamento;
static float carrierScalar;
static float carrierFreq;
static long carrierFreqReading;
static float previousCarrierFreq;

static long modulatorDepthReading;
static Port modulatorDepthPortamento;
static float modulatorDepth;

static long modulatorRatioReading;
static Port modulatorRatioPortamento;
static float modulatorRatio;

static Cubicnl distortionl, distortionr;
static long distortionLevelReading;
static Port distortionLevelPortamento;
static float distortionLevel;

static Tremor tremolo;
static Port tremoloDepthPortamento;
static long tremoloDepthReading;
static float tremoloDepth;
static Port tremoloWidthPortamento;
static long tremoloWidthReading;
static float tremoloWidth;
static Port tremoloFreqPortamento;
static long tremoloFreqReading;
static float tremoloFreq;
static float tremoloScalar;

const float kTremoloFreqLow = 1.0;
const float kTremoloFreqHigh = 13.0;

const float kChorusPanWidth = 0.5;  // values 0-1, 0 meaning no witdth, 1 meaning full width.
static Chorus chorus;
static Port chorusDepthPortamento;
static long chorusDepthReading;
static long chorusDepth;

DaisyHardware hw;
size_t numChannels;


void MyCallback(float **in, float **out, size_t size) 
{
  float slewedVolumeLevel, slewedGain; 
  float slewedCarrierFreq, slewedModulatorDepth, slewedModulatorRatio;
  float slewedDistortionLevel;
  float slewedChorusDepth;
  float slewedTremoloDepth, slewedTremoloWidth, slewedTremoloFreq;
  float gainOut, envelopeOut, modulator, sig, sigl, sigr;

   for (size_t i = 0; i < size; i++) 
   {
      slewedGain = gainPortamento.Process(gain);
      envelopeOut = envelope.Process(gate) * slewedGain;
      slewedVolumeLevel = volumePortamento.Process(volumeLevel);

      if(gate == true) 
      {
        previousCarrierFreq = carrierFreq;
        slewedCarrierFreq = carrierPortamento.Process(carrierFreq);
        previousCarrierFreq = slewedCarrierFreq;
      }
      else 
      {
        slewedCarrierFreq = carrierPortamento.Process(previousCarrierFreq);
      }
      slewedModulatorRatio = modulatorRatioPortamento.Process(modulatorRatio);
      slewedModulatorDepth = modulatorDepthPortamento.Process(modulatorDepth);

      fmOsc.SetAmp(envelopeOut);
      fmOsc.SetRatio(slewedModulatorRatio);
      fmOsc.SetDepth(slewedModulatorDepth);
      fmOsc.SetFreq(slewedCarrierFreq);
      sig = fmOsc.Process();

      slewedChorusDepth = chorusDepthPortamento.Process(chorusDepth);
      float depth = fmap(slewedChorusDepth, 0.0, 0.8);
      chorus.SetLfoDepth(depth);
      float feedback = fmap(slewedChorusDepth, 0.2, 0.9);
      chorus.SetFeedback(feedback);
      chorus.Process(sig);
      sigl = chorus.GetLeft() + sig * 0.707 * 0.5;
      sigr = chorus.GetRight() + sig * 0.707 * 0.5;

      slewedDistortionLevel = distortionLevelPortamento.Process(distortionLevel);
      distortionl.SetDrive(slewedDistortionLevel);
      distortionr.SetDrive(slewedDistortionLevel);
      float dryl, dryr, scaled;
      scaled = pow(slewedDistortionLevel, 0.2f);
      dryl = sigl * (1.0f - scaled);
      dryr = sigr * (1.0f - scaled);

      sigl = distortionl.Process(sigl) + dryl;
      sigr = distortionl.Process(sigr) + dryr;

      slewedTremoloFreq = tremoloFreqPortamento.Process(tremoloFreq);
      slewedTremoloDepth = tremoloDepthPortamento.Process(tremoloDepth);
      slewedTremoloWidth = tremoloWidthPortamento.Process(tremoloWidth);
      tremolo.SetFreq(slewedTremoloFreq);
      tremolo.SetDepth(slewedTremoloDepth);
      tremolo.SetWidth(slewedTremoloWidth);
      float trem = tremolo.Process();
      float treml = tremolo.GetLeft();
      float tremr = tremolo.GetRight();

      sigl = sigl * trem * treml;
      sigr = sigr * trem * tremr;

      out[0][i] = sigl * slewedVolumeLevel;
      out[1][i] = sigr * slewedVolumeLevel;
   }
} // end MyCallback


float normalizeSoftpot(long sensorValue) 
{
  long value;
  float normalizedValue;
  value = constrain(sensorValue, kSoftPotThreshold, kAdcMax);
  value = map(value, kSoftPotThreshold, kAdcMax, 0, kAdcMax);
  normalizedValue = (float)value/(float)kAdcMax;
  return normalizedValue;
}


float normalizeForceSensor(long sensorValue) 
{
  long value;
  float normalizedValue;
  value = constrain(sensorValue, kForceSensorThreshold, kAdcMax);
  value = map(value, kForceSensorThreshold, kAdcMax, 0, kAdcMax);
  normalizedValue = (float) value / (float) kAdcMax;
  if (normalizedValue > kGateThreshhold) {
    gate = true;
  }
  else {
    gate = false;
    //Serial.println("Gate Off");
  }
  return normalizedValue;
}
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

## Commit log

2023-10-03 completed working code with exception of noise or reverb
    [enclosure-v2.dxf]
2023-10-04 add noise and reverb. set modulation rate to static value. changed layout of knobs
    [absonus.ino]
2023-10-11 added drawings
    [enclosure-v2.dxf, ribbon-panel.dxf]
2026-04-06 Update .gitignore, Design Notes.pages, enclosure-v2.dxf, and ribbon-panel.dxf
    [enclosure-v2.dxf, ribbon-panel.dxf]
2026-04-06 added all components.
    [#bud-cu-477-drill-patterns.dxf, #internal-drill-holes.dxf, #ribbon-panel-top.dxf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]
2026-04-06 Reorganize project structure and add firmware documentation
    - Introduce docs/, firmware/, hardware/, bom/, assets/, archive/ layout
    - Move absonus-v0.1 → firmware/absonus (canonical firmware, .ino renamed)
    - Move absonus-sensor-test → firmware/sensor-test
    - Archive old firmware prototypes (fm, fm-chorus, tremor, sensor-test, absonus v0)
    - Move enclosure/, testing-panel/ → hardware/
    - Restructure pcb/: v0.2 and battery-clamp stay current; v0.1, lipo-charger-booster,
    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
    [#bud-cu-477-drill-patterns.dxf, #internal-drill-holes.dxf, #ribbon-panel-top.dxf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]
2026-04-06 Ignore and untrack KiCad/FreeCAD backup and cache files
    Patterns added to .gitignore:
    *-backups/ KiCad auto-save backup directories
    production/backups/
    fp-info-cache KiCad footprint cache (regenerated on open)
    *.kicad_sch-bak KiCad schematic backup
    *.kicad_prl KiCad per-project local settings
    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
2026-04-06 Add hardware verification section to README describing sensor-test
2026-04-06 Updated KiCAD files to latest version. output PDFs
    [absonus-v0.2-B_Cu.gbr, absonus-v0.2-B_Mask.gbr, absonus-v0.2-B_Paste.gbr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]

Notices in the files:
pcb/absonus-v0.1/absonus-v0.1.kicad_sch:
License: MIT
